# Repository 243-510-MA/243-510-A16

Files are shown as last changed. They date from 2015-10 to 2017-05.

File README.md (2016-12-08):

# 243-510-A16
243-510 Communications numériques sans fil - automne 2016 Collège de Maisonneuve

Notre projet est de réaliser un système dynamique contrôlable à distance à l'aide d'un réseau MiWi pour faciliter le travail et la vie des étudiants et professeurs du département du Génie électrique du Collège de Maisonneuve. Le projet comporte un système d'alarme qui s'enclenche lorsqu'il y a détection de mouvement, avec un gyrophare et un avertisseur sonore (buzzer), un contrôleur magnétique pour déverrouiller une porte, un contrôleur qui permet de contrôler un projecteur et une toile et l'envoi de messages prédéfinis à une adresse spécifique.

Parties fonctionnelles :

    Contrôle du projecteur (ON/OFF) à l'aide d'une communication série (RS-232)(BAUD 9600)(LSB(inverted?)) :

    Trames utilisées :

    Power on
        0x00 0xBF 0x00 0x00 0x01 0x02 0xC2
        0x02 0x00 0x00 0x00 0x00 0x02

    Power off
        0x00 0xBF 0x00 0x00 0x01 0x00 0xC0
        0x02 0x00 0x00 0x00 0x00 0x03

    Le contrôle de la toile à l'aide d'un servomoteur.
    Le contrôle de la porte à l'aide d'un électroaimant.
    L'envoi d'un questionnaire par le professeur aux élèves avec les réponses affichées sur l'écran du module professeur.
    Le gyrophare et le buzzer fonctionnent.
    Le chargeur du module étudiant (prototype) fonctionne.
    Les modules peuvent tous contrôler les options en réseau MiWi (PAN et end-devices).
	Le détecteur de mouvement fonctionne.
	L'envoi de messages prédéfinis à une adresse choisie.
	L'envoi de commandes MiWi à partir du terminal (sur le port série)

Parties non fonctionnelles :

	[PROBLÈME NON RÉSOLU]Lors de la réception de messages, on souhaitait afficher l'adresse source (de quel adresse le message est-il envoyé), mais on n'a pas trouvé comment effectuer cela.

Bugs connus à résoudre pour avoir un fonctionnement parfait :

    [PROBLÈME TROUVÉ, MAIS NON RÉSOLU]Le projecteur ne répond pas lorsque certaines conditions sont remplies. Si la lumière verte de "STATUS" est éteinte et que le bouton "power" est orange, le projecteur ne réagit pas aux communications séries (RS-232). La solution pour résoudre le problème est d'ajouter les trames de débuts manquantes dans l'envoi d'un message RS-232. Le contrôleur doit envoyer une trame de "wake-up" au projecteur à chaque 7 secondes environ pour s'assurer qu'il est prêt à "écouter" sur le bus. La trame de "wake-up à ajouter est : 0x00 0xBF 0x00 0x00 0x01 0x00 0xC0.
	[PROBLÈME TROUVÉ, MAIS NON RÉSOLU]Lors de la synchronisation de nouveaux fichiers sur GitHub, le fichier Demo911.c et le fichier Demo911.h se retrouvent supprimés du projet. Il y a un problème au niveau de la façon dont ont commit nos fichiers sur GitHub.
	
Étudiants contributeurs : François D'Amours-Lavoie, Mathieu Labelle, Laurent Brochu, Jonathan Chouinard, Alexandru Marin, Étienne Vaillancourt, Renaud Varin, Dominic Fournier, Dominik Boudreau-Perron, Gabriel Ahr, Alexia Brazeau, Samuel Proulx, Jean-Philippe Dagenais, Carlos Bedoya

Professeur contributeur : Frédéric Daigle

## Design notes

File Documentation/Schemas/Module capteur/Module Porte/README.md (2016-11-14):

Pour Calculer la Résistance nécessaire pour le 
courant de la base il faut utiliser la formule suivante
Ic = hfe * Ib

Ic= courant collecteur
hfe= Gain du transistor bijonction
Ib= Courant a la base

Dans notre utilisation, l'electro aimant consomme
200mA max. mais la limite du transistor est de 200mA
donc on a decicé de l'alimenter avec 190mA. 
Donc Ic=190mA

Pour calculer le hfe il faut utiliser le multimetre sur 
option NPN.   hfe = 189

avec la formule on deduit que Ib nécessaire est de 1mA.

ensuite pour trouver la resistance on utilise la loi de ohm.
R=V/I (il ne faut pas oublier de soustraire 0.7V de la tension
 au signal du a la chute de tension du transistor.

V= (3.3 - 0.7) = 2.6V

R= 2.6 / 1mA = 2600 Ohms.

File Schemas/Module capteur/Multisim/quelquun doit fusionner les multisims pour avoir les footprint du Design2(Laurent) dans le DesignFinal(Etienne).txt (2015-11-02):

quelquun doit fusionner les multisims pour avoir les footprint du Design2(Laurent) dans le DesignFinal(Etienne)

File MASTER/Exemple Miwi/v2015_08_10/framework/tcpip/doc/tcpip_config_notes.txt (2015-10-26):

Items that cannot be enabled in tcpip_config.h:

For Demo App:
None
  Following items cannot be enabled when using PIC 18:
  STACK_USE_SSL_SERVER
  STACK_USE_SSL_CLIENT
  STACK_USE_TCP_PERFORMANCE_TEST
  STACK_USE_ZEROCONF_LINK_LOCAL
  STACK_USE_ZEROCONF_MDNS_SD
  STACK_USE_GENERIC_TCP_CLIENT_EXAMPLE behaves incorrectly
  STACK_USE_TELNET_SERVER and STACK_USE_SNTP_CLIENT cannot be enable simultaneously. Either one of them can be enabled.

WiFi Console:
STACK_USE_HTTP2_SERVER
STACK_USE_SSL_SERVER can be enabled with cert file: custom_ssl_cert.c
STACK_USE_SSL_CLIENT can be enabled with cert file: custom_ssl_cert.c
STACK_USE_AUTOUPDATE_UART (only can not be enabled in MRF24WB)
STACK_USE_SNTP_CLIENT will make the console slow in some configurations

Easy Config:
STACK_USE_SSL_SERVER can be enabled with cert file: custom_ssl_cert.c
STACK_USE_SSL_CLIENT can be enabled with cert file: custom_ssl_cert.c

WiFi G Demo:
STACK_USE_UART
STACK_USE_UART2TCP_BRIDGE
STACK_USE_SSL_SERVER can be enabled with cert file: custom_ssl_cert.c
STACK_USE_SSL_CLIENT can be enabled with cert file: custom_ssl_cert.c
STACK_USE_FTP_SERVER (lack of EEPROM which is used by some functions)
STACK_USE_TELNET_SERVER (lack of LEDs or Buttons)
STACK_USE_UDP_PERFORMANCE_TEST (lack of LEDs or Buttons)

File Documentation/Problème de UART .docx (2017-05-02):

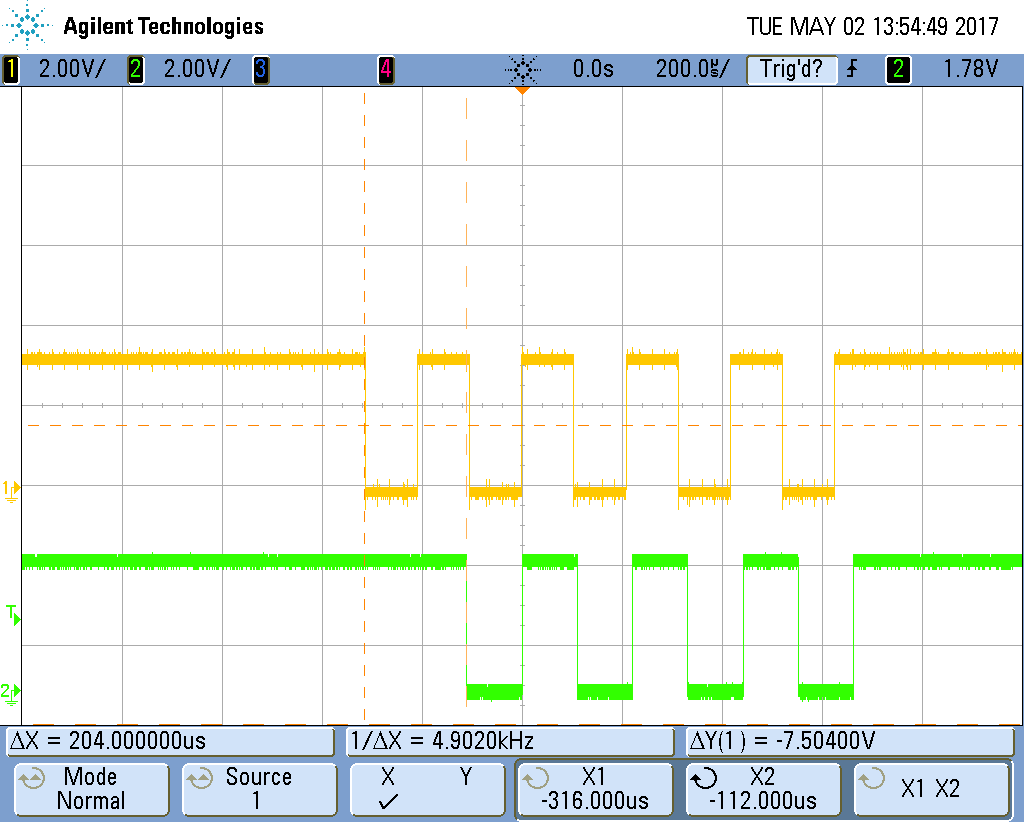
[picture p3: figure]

Problème de UART

Signal vert : moment ou le microcontrôleur utilisant le UART logiciel fait un échantillon de la broche de réception.

Signal jaune : Caractère 'U' envoyé à partir de Tera Term sur le port série

Explication :

Le UART matériel des modules MIWI est déjà utilisé par l'antenne MiWi, et il y en a un seul sur le PIC utilisé (PIC18F46J50). Il y a alors du code (soft_uart.c) pour un UART logiciel (fonctions avec le suffixe « A2_A1 « , tel que UART_Read_A2_A1) . Cependant, puisque c'est logiciel et qu'il n'est pas basé sur des temporisateurs, ainsi que le fait que la lecture de la broche ne peux pas se faire par interruption (cette broche là ne le permet pas et il n'y a qu'une broche d’interruption sur ce PIC), la lecture des données entrants n'est pas fiable du tout. L'envoi de données l'est un peu plus, mais pas à 100%. L'envoi de données peut se faire interrompre par des routines d'interruptions de temporisateurs ou d'interruptions externes (le UART de l'antenne MiWi par exemple).

Sur la capture d'écran, on voit que l'échantillonnage qui est supposé se faire après 150 us (50 us de start bit, + 100 us pour échantillonné au milieu du bit) se fait à 204 us, dans ce cas ci. Le moment d'échantillonnage variera selon le moment d'envoi des données sur la broche de réception du PIC ainsi que l'endroit dans le code ou le PIC est rendu à exécuter (variation du délai avant que le programme exécute « if(uart_kbhit()) ».

Idéalement, il faudrait un PIC différent qui a deux UART matériel, ou mettre le UART logiciel sur une broche qui peut être interrompue.

Une autre solution (possiblement) serait de suivre le modèle de la fonction « questionnaire_function » dans « student.c » . Il faudrait placer le « if(kbhit()) » à plusieurs place dans les autres fonctions exécutées par le module COMPUTER_CONTROL.

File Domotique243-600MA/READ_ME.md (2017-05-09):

243-600 Systèmes d'exploitation
===============================
Projet domotique
----------------
#Avant de continuer le projet, assurez vous d'avoir effectué toutes les installations nécéssaires sur le beaglebone qui sont sur le fichier => Étapes d'installation. 

Dans le cadre du cours 243-600 on doit ajouter des fonctionnalités au projet de la classe intelligente réalisé dans le cours de Communication numérique sans-fil. 
On doit être capables de faire:

*Une visualisation des conditions atmosphériques de la classe à partir de n'importe quel ordinateur connecté à Internet.
*Faire une visualisation de l'état de la Porte à partir de n'importe quel ordinateur connecté à internet
*Avoir la possibilité pour un professeur de verrouiller ou déverrouiller la classe à pârtir de n'importe quel ordinateur connecté à internet.
*Possibilite de savoir par internet qui est présent dans la classe
*Affichage d'un message envoyé par Internet sur l'écran OLED du Beaglebone
*Toute autre fonctionnalité jugée utile ou intéressante

Ce qui a été complété jusqu'a maintenant à la date du : 09/Mai/2017

* La visualisation des conditions atmosphériques de la classe à partir de n'importe quel ordinnateur connecté à internet.
>on a reussi à lire les données sur le capteur meteo BME_280 et de mettre les données >sur un fichier json. (Donnee_BME280.json) qui est sauvegarde sur /home/debian du >Beaglebone. Le code qui s'occupe de tout faire cela est dans le fichier Station_Meteo/ >Capteur. Capteur est le code source qui doit être compilé et mis dans le beaglebone.

*Visualisation de l'état de la porte à partir de n'importe quel ordinateur connecté à internet.
>Sur le dashboard: Classe intelligente sur Adafruit( username:243600MA MDP:temppwd)
>il y a un «feed» qui est un bouton(Status Porte) et auquel on peut changer l'état à >partir du beaglebone et l'inverse aussi sauf qu'il faut vérifier l'état à chaque >fois, >ce qui crée du traffic non-nécéssaire. 

*Possibilité, pour un proffesseur, de verouiller ou de deverrouiller la classe à partir de n'importe quel ordinnateur connecté à internet.
>CE QU'IL FAUT FAIRE: c'est trouver comment faire la communication avec le protocole >MQTT qui nous permettrait d'utiliser la fonction Subscribe. On retrouve l'information >sur:https://github.com/adafruit/io-client->python/blob/master/examples/mqtt_client.py
>Avec mqtt on aura pas besoin de toujours vérifier l'état puisque le server va dire au >Beaglebone dès qu'une modification a été faite sur le dashboard.

*Possibilité de savoir par internet qui est présent dans la classe
>Pour les modules MiWi, les modules en student sont capables d'envoyer leur addresse >MAC au module Computer Control a chaque minute. Le computer control les recoit mais  >fait rien à cause que ce n'est pas encore implementé. 
>il resterait a implementer un code qui envoie cette information au Beaglebone aussi >et a partir du Beaglebone envoyer cette info au Dashboard du serveur Adafruit.io 
>Il y a une document sur github qui explique le problème qu'il y a sur le UART du >Computer Control.

*Affichage d'un message envoyé par internet sur l'écran OLED du Beaglebone
>On est capables d'afficher un message sur le Beaglebone qui provient du Dashboard >sauf qu'ici encore on doit le vérifier au lieu de recevoir un avertissement qui >provient du serveur quand il a été changé. il faut trouver une facon de faire >fonctionner le MQTT

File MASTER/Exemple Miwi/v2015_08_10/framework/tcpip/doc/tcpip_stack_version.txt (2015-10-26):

********
Microchip TCP/IP Stack Version Log:
********

Note: Please file bug-reports/bug-fixes at http://support.microchip.com/ or post
      to the Microchip TCP/IP -> Ethernet Forum at http://forum.microchip.com/
      Look for stack updates at http://www.microchip.com/mla/

********
v5.45.00    August 2015
********
Changes:
1. Minor changes to fit latest version of XC8, XC16 and XC32 compilers.

********
v5.44.00    May 2015
********
Wi-Fi Changes:
1. For connection to AP in Infrastructure, WPS, or network redirection from SoftAP or Ad-Hoc mode, client station defaults to WPA-PSK/WPA2-PSK Auto when AP is in WPA-PSK, WPA2-PSK, WPA-PSK/WPA2-PSK Auto, or WPA-PSK/WPA2-PSK Mixed mode.
2. Improve DHCP Server to support up to 6 clients and recycle IP when lease expired or client disconnected.

Wi-Fi Notes:
1. MRF24WB WPA-PSK/WPA2-PSK Auto mode may not work when the target AP is set at WPA-PSK/WPA2-PSK Auto/Mixed mode.  The solution is to set WPA-PSK or WPA2-PSK mode in AP.
2. Current Wi-Fi Demo Projects do not support MPLAB Code Configurator.

Wi-Fi G Demo Improvements:
1. DHCP Server
    - support up to 6 clients
    - recycle lease IP when client disconnected - enable/disable this feature with #define CHECK_LINK_STATUS
    - longer ACK timeout to better accommodate busy wireless network
2. Wireless Security Mode
    - client station uses WPA-PSK/WPA2-PSK Auto when connecting to AP in WPA-PSK, WPA2-PSK, or WPA-PSK/WAP2-PSK Auto/Mixed mode

Fixes:
1. Fixed mDNS indexes overrun bug to handle incoming message with length greater than 8 bits value.

********
v5.43.00    July 2014
********
Changes:
1. Ported WiFi support from legacy MLA.
2. SNMP support has not been ported.
3. SSL is no longer supported for PIC18 and XC8.
4. Improve OTA update. Uses .txt as well as .bin.
5. Improve WPA/WPA2 mixed mode behavior.
7. TCPIP Configuration Wizard utility has not been ported.

Fixes:
1. WiFi G demo scan lock-up problem.
2. Address TCP 0 length lock-up problem.
3. Improve RawMoveComplete lock-up problem.
4. Fix wrong RSSI indications.
5. Address SSL 2048 problem.

********
v5.42.08    June 2013
********
Changes:
1. Clarify item#4 in v5.42.04 Oct 2012 release. Change is applicable to MRF24WB/G only.
   (MRF24WB/G) SSL client with RSA 2048bits is enabled by default. Applies only for PIC24/32. Not supported for PIC18.
2. (WiFi G Demo Board) Disable option WF_EASY_CONFIG_DEMO in WF_Config.h to resolve compilation error with IperfAppInit().

Fixes:
1. (MRF24WB) Resolve firmware 0x120C host scan bug : Host scan asserts when it is conducted after WPA-PSK fails due to key mismatch.
   Refer to WFScan.c and WFMgmtMsg.c.
2. (MRF24WB) Resolve reset problem bug. Modified WF_SetCE_N and WF_SetRST_N to first set the level, than configure pin as output.
   Refer to WFDriverPrv.h. This change is already available in WFDriverPrv_24G.h for MRF24WG in MLA v5.42.02 Aug 2012 release.
3. (MRF24W) Resolve WiFi Console demo IPERF issue bug fix : Enlarge generic tcp rx/tx buffer size. Refer to TCPIP MRF24W.h.
4. (MRF24W) Resolve EasyConfig bug fix for retry count when DISABLE_MODULE_FW_CONNECT_MANAGER_IN_INFRASTRUCTURE is enabled.
   Refer to function WFEasyConfigProcess() in WFEasyconfig.c
5. (MRF24W) Resolve handling of max length SSID of AP. Refer to WFEasyConfig.c and CustomHTTPApp.c

********
v5.42.06    Feb 2013
********
Changes:
1. (MRF24WG)   Due to memory constraints, all future RF module FW releases will follow this roll-out order
               (Odd number eg 0x3109, 0x310b) Differences: Supports Wi-Fi Direct (P2P). But no EAP and no multi-client support.
               (Even number eg 0x3108, 0x310a) Differences: Supports EAP (with MCHP approval) and multi-clients. But no Wi-Fi Direct support.
2. (MRF24WG)   Added new project Wifi G demo. Wifi G demo currently only support softAP function,
3. (MRF24WG)   In Wifi Console, for XC32-EX116-EAP_MRF24WG, supports security mode WF_SECURITY_WPA2_ENTERPRISE
               (EAP-PEAP/MSCHAPv2 and EAP-TTLS/MSCHAPv2) .
               Requires RF module FW version 0x3108 and even number releases. This requires special approval submitted to marketing.
4. (MRF24WG)   Supports multi-client DHCP server (max 4 clients). SoftAP supports up to max 4 client
               Requires RF module FW version 0x3108 and even number releases.
5. (MRF24WG)   softAP supports active scan. Requires RF module FW version 0x3108 and future releases.
6. (MRF24WG)   RF module FW version 0x3107 and future releases will NO longer support programming of regional domain via function
               WF_SetRegionalDomain() due to changes in FCC requirements, which does not allow programming of the regional domain.
7. (MRF24WB/G) Only WEP key index 0 is valid for security mode WEP.
8. (MRF24WG)   Created new event WF_EVENT_SOFT_AP_EVENT_SUBTYPE / WF_EVENT_SOFT_AP_EVENT, for softAP mode, to indicate client's
               status (connected or disconnected to softAP). Requires RF module FW version 0x3108 and later releases. If prior
               MLA releases are used with this new RF module FW version release, you need to port over this event handling in
               WFEVentHandler.c and WF_ProcessEvent() (WiFi EZConfig).
9.             Added full versions of RSA.c, ARCFOUR.c, and AES_PIC32MX.a to the TCP/IP Stack Distribution to support SSL and SNMPv3.
               Previously these files were distributed in a separate cryptographic code distribution.  These files are subject to the
               U.S. Export Administration Regulations and other U.S. law, and may not be exported or re-exported to certain countries
               or to persons or entities prohibited from receiving U.S. exports (including Denied Parties, entities on the Bureau of
               Export Administration Entity List, and Specially Designated Nationals).

Fixes:
1. (MRF24WG)   In EZConfig, SoftAP now supports Zeroconf & mDNS. Resolves wrong port issue.
               Search for keyword SOFTAP_ZEROCONF_SUPPORT.

********
v5.42.04    Oct 2012
********
Changes:
1.  (MRF24WB/G) Patch update features are added into MRF24WB0MA/B and MRF24WG0MA/MB.
    MRF24WB0MA/B (no RF module FW version update is necessary)
            Serial Port (Xmodem)
    MRF24WG0MA/B (Requires RF module FW version 3107 or later.)
            Serial Port (Xmodem), Web Client, Web Server
2.  (MRF24WB/G) FTP client is added into WiFi console demo app.
3.  (MRF24WB/G) Flexible scratch memory is used to allocate TCB.
4.  SSL client with RSA 2048bits is enabled by default. Applies only for PIC24/32. Not supported for PIC18.
5.  16-bit mode feature is available on PIC32.
6.  (MRF24WG) Enhance SoftAP with EZConfig features with pre-scan and redirection features.
    Change SoftAP address from 192.168.1.1 to 192.168.1.3
    Added WEP security, which requires RF module FW version 3107 or later.
    Refer to WF_Config.h for more information.
7.  Added support for PIC32MX6XX external PHY's: RTL 8201FL.
    Only RMII configuration is supported with RTLPHY8201FL PHY.
    This PHY driver works in Default Ethernet IO mode with PIC32MX675F512H .
    If Alternate Ethernet IO mode is used for other PIC devices, then configuration bit need
    to be changed w.r.t Alternate Ethernet IO.
    To get the status of MAC link with this PHY,  PHY Link Status need to be read twice.
    EthPhyGetLinkStatus(int refresh) API is used to read the PHY link status and for this PHY
    to read link status twice, the parameter refresh should be 1.

Fixes:
1.  (MRF24WG) SoftAP under EZConfig has pre-scan and redirection features. Able to be redirected to infrastructure mode AP.
2.  If SNMP_TRAP_DISABLED macro is enabled from TCPIP XXX.h file, there will be no TRAP table information for SNMP manager.
    That is SNMP agent won't send information related to trap. By default SNMP_TRAP_DISABLED macro is disabled.
3.  Fix typo error in v5.42.02
    (MRF24WG) SoftAP default address is changed from 169.254.1.1 to 192.168.1.1
4.  Fixed SNMP tabular issue if SNMP instances starts other than 0.
5.  Fixed ARP initialization bug that resulted in TCP packets sent to ETH MAC broadcast address.

********
v5.42.02    Aug 2012
********
Fixes:
1.  (MRF24WB/G) TCPIPConfig.exe is modified to support changes in macro definitions (CFG_WF_INFRASTRUCTURE, CFG_WF_ADHOC)
    used in WF_Config.h.
2.  (MRF24WB/G) Ad-hoc mode was left out in the TCPIP-Demo app. This mode is reinstated back into TCPIP-Demo app.
    2 files are changed.
    .\Microchip\Include\TCPIP Stack\WFDebugStrings.h
    .\TCPIP\Demo App\WF_Config.h
3.  (MRF24WB/G) SoftAP default address is changed from 192.168.1.1 to 169.254.1.1
4.  (MRF24WG) Apply SSL fix.
    Root cause is traced to be due to scratch pad memory to memory copy functions in WFMac_24G.c
5.  (MRF24WG) Reset fix.
     a.  In file WFDriverCom_24G.c, MRF24WG reset sequence is modified.
         - WFHardwareInit() does hard reset (putting I/O lines in correct state)
         - ChipReset() does soft reset
     b.  In file WFDriverPrv_24G.h, macros WF_SetCE_N() and WF_SetRST_N() modified to first set the output level,
         then set the I/O direction
6.  (MRF24WG) Applies to using PICDEMNet2 board and PIC18. Related to SPI interface settings.
     a.  In file WF_Spi.c, ConfigureSpiMRF24W() modified, for PIC18 only, to change the SPI clock idle state to low.
7.  (MRF24WB/G) When host attempts to read scan results while the module FW is in reconnecting state,  the module FW
    returns WF_ERROR_NO_STORED_BSS_DESCRIPTOR error. Reading scan results is only allowed in A) connected state; B) idle state.
    Fix is in WaitForMgmtResponseAndReadData().

    void WaitForMgmtResponseAndReadData(UINT8 expectedSubtype, UINT8 numDataBytes, UINT8 startIndex, UINT8 *p_data)
    {     ....................................
          /* check header result and subtype fields */
          WF_ASSERT(hdr.result  == WF_SUCCESS || hdr.result == WF_ERROR_NO_STORED_BSS_DESCRIPTOR);
          WF_ASSERT(hdr.subtype == expectedSubtype);
          ....................................
    }

********
v5.42       Jul 2012
********
Changes:
1.  All MPLAB 8 and MPLAB X projects have been modified to use the XC16 and XC32 compilers.
2.  The colon character ":" has been added as a valid terminator for an IP address in
    the StringToIPAddress function.
3.  (MRF24WB/G) PIC18 is only supported with "TCPIP Demo App".
    MRF24WB0MA/MB works on PICDEM PIC18 Explorer.
    MRF24WG0MA/MB works on PICDemNet2 PIC 18 but has issues with PICDEM PIC18 Explorer.
4.  (MRF24WB/G) Enhanced debug messages providing more details such as authentication or association
     failues, etc.
5.  (MRF24WB/G) Added option to disable module FW connection manager by adding "#define DISABLE_MODULE
    _FW_CONNECT_MANAGER_IN_INFRASTRUCTURE".
6.  (MRF24WB/G) Added option to derive real key from pass-phrase in host side by adding "#define DERIVE
    _KEY_FROM_PASSPHRASE_IN_HOST".
7.  (MRF24WB/G) Enabled WEP security for EasyConfig Ad-hoc connection
8.  (MRF24WB/G) Added support for MRF24WG0MA/MB, a superset of MRF24WB0MA/MB (MRF24WB).
    Required to add to project definition files (#define MRF24WG).
    Ranges are different from MRF24WB0MA/MB.
    i.   Valid RSSI Range : 43 ~ 128 (max)     (WF_ScanGetResult())
    ii.  Max transmit power range : 0 ~ 18 dbm (WF_TxPowerSetMax())

    MRF24WG0MA/MB enhancements are above and beyond on those features listed above.
    a.   Added WPS(1.0) security method (#define WF_SECURITY_WPS_PUSH_BUTTON & WF_SECURITY_WPS_PIN )
         (TCPIP demo + console demo).
    b.   Added Wi-Fi Direct (P2P) function in the GC (group client) role
         (#define MY_DEFAULT_NETWORK_TYPE    CFG_WF_P2P)
         (TCPIP demo + console demo)
    c.   Added simplified basic SoftAP functionality (WF_SOFT_AP).
         Current features are 1 client STA, open security and no routing.
         (Easy config demo)
    d.   Selection of support for 16 (max) software multicast filters (ENABLE_SOFTWARE_MULTICAST_FILTER )
         or 2 hardware multicast filters. RTS or ES release requires software patch.

Fixes:
1.  The BigInt_helper.S file will now correctly include the processor include files for the
    PIC24E and dsPIC33E architectures.
2.  Fixed bug in TCP state machine that corrupted the sequence number when client socket is closed.
3.  Fixed bug in BerkeleiAPI.c::sendto() that checked for the wrong UDP socket to be opened.
4.  (All parts including RTS or ES release) MRF24WG0MA/MB requires PLL work-around initialization code.
    Please refer to July/2012 release.
5.  (All parts including RTS or ES release) MRF24WG0MA/MB needs to update stack from July/2012 release
    to cater for SSL.
6.  (MRF24WB/G) Fixed stack issues encountered in Stack version v2012-04-03 and older.
    Code fix is needed in WF_CPSetElements() API. Modification is as below.

    void WF_CPSetElements(UINT8 CpId, tWFCPElements *p_elements) {
         UINT8 elements[sizeof(tWFCPElements) + 2];
         WF_ASSERT(p_elements->ssidLength <= WF_MAX_SSID_LENGTH);
         memset(elements, 0, sizeof(elements));
         memcpy(elements, p_elements, sizeof(*p_elements));
         LowLevel_CPSetElement(CpId,                 /* CP ID */
                               WF_CP_ELEMENT_ALL,    /* Element ID */
                               (UINT8 *)elements,    /* pointer to element data */
                               sizeof(elements));    /* number of element data bytes */
     }

    Code fix is also needed in WaitForMgmtResponse() API (WFMgmtMsg.c). Refer to description
    of this fix is in the Supplementary TCPIP Help folder.

Known Problems:
1.  Telnet server module does not implement a lot of Telnet functions.  As a
    result, it will likely not display correctly or work at all with some Telnet
    clients.  The server was tested with the Microsoft telnet.exe utility which
    is provided with Microsoft Windows.
2.  If the DHCP client and DHCP server are used at the same time and you connect
    two similar boards to each other (ex: two PICDEM.net 2 boards connected via
    a crossover cable), a race condition can occur where both nodes will disable
    their DHCP server and neither board will get a successful DHCP lease.  If
    this unlikely scenario occurs, as a work around, simply reset one of the
    boards to reenable it's DHCP server.
3.  LCDBlocking.c timing for the LCD_E_IO enable signal is too fast to meet
    published data sheet limits for various LCD controllers when compiling for
    a PIC32 running at > 43MHz.  Despite this potential timing violation, the
    LCD does normally work correctly on the precompiled PIC32 demos for the
    Explorer 16 at 80MHz.
4.  For PIC32 implementations, depending on the configuration, it is possible that the
    MACGetFreeRxSize() returns a value greater than 64 KB.
    For backward compatibility reasons the stack uses a 16 bit value to check the returned value
    and it won't work corretly.
5.  Limiting the number of UDP sockets to 8 in the stack demos may prevent SNMP trap
    functionality.  If this occurs, you can increase the MAX_UDP_SOCKETS definition in
    TCPIPConfig.h to 10 (if your system will support the increased data memory usage)
    to fix this issue.
6.  The SNMP mib file's date and version parameter does not match the date/version of
    the current stack release.
7.  (MRF24WG0MA/MB) RTS or ES release requires software patch for multicast filters.
8.  (MRF24WG0MA/MB) Under softap option with easy config demo, unable to connect to infrastructure mode AP.
9.  Certain APs have power save issue with reconnect. Please refer to AP compatibility list.

********
v5.41.02    Apr 2012
********
Fixes:
1.  Added the Bigint helper libraries for C30 into the stack source folder to prevent
    linker errors in 16-bit projects that include those libraries.

Known Problems:
1.  Telnet server module does not implement a lot of Telnet functions.  As a
    result, it will likely not display correctly or work at all with some Telnet
    clients.  The server was tested with the Microsoft telnet.exe utility which
    is provided with Microsoft Windows.
2.  If the DHCP client and DHCP server are used at the same time and you connect
    two similar boards to each other (ex: two PICDEM.net 2 boards connected via
    a crossover cable), a race condition can occur where both nodes will disable
    their DHCP server and neither board will get a successful DHCP lease.  If
    this unlikely scenario occurs, as a work around, simply reset one of the
    boards to reenable it's DHCP server.
3.  LCDBlocking.c timing for the LCD_E_IO enable signal is too fast to meet
    published data sheet limits for various LCD controllers when compiling for
    a PIC32 running at > 43MHz.  Despite this potential timing violation, the
    LCD does normally work correctly on the precompiled PIC32 demos for the
    Explorer 16 at 80MHz.
4.  For PIC32 implementations, depending on the configuration, it is possible that the
    MACGetFreeRxSize() returns a value greater than 64 KB.
    For backward compatibility reasons the stack uses a 16 bit value to check the returned value
    and it won't work corretly.
5.  Limiting the number of UDP sockets to 8 in the stack demos may prevent SNMP trap
    functionality.  If this occurs, you can increase the MAX_UDP_SOCKETS definition in
    TCPIPConfig.h to 10 (if your system will support the increased data memory usage)
    to fix this issue.
6.  The SNMP mib file's date and version parameter does not match the date/version of
    the current stack release.

********
v5.41       Feb 2012
********
Changes:
1.  Added socket number validation to TCP functions.
2.  Removed the WiFi projects from the Energy Monitoring and WebVend demos.
3.  Added the "-mperipheral-libs" linker option to C32 projects.
4.  Moved AES library and header files used by SNMPv3 from the "Crypto" source and
        include folders to the to the "TCPIP Stack" source and include folders.
5.  Changed SNMP MIB trap number from 7 to 0.
6.  Changed SNMP MIB SYOBJECTID to 43.6.1.4.1.17095.1 (added .1).
7.  Updated MPFS2 Utility to make path settings persistent.
8.  Changed default channel list from {1,6,11} to {1,2,3,4,5,6,7,8,9,10,11} for
    FCC domain
9.  Added support for WEP with Shared Key
10. Added new command "iwconfig scan" & "iwconfig scanresults"
11. Added gRFModuleVer1209orLater" flag to identify version 1209 and later
    specific API's.
12. Added the following 1209 and later specific API:
    a) WF_CPSetWepKeyType()
    b) WF_CMGetConnectContext()
    c) WFEnableBroadcastProbeResponse()
    d) WFEnableAggressivePowerSave()
    e) WF_CPSetSsidType()
    f) WFEnableDeferredPowerSave()
    g) WF_FixTxRateWithMaxPower()

Fixes:
1.  Updated MPFS2 Utility path strings for Mac/Linux compatibility.
2.  Iperf - Resolved application crash due to network disconnection.
3.  Host Scan - More robust and prevent system hang up.  #define WF_HOST_SCAN.
4.  Power Save - Improvements with Aggressive PS mode, and better handling of
    PS in host code.
5.  Host connect & disconnect - Prevent system hang.
6.  DHCP Refresh - Better handling of DHCP session in PS mode, and issue DHCP
    renewal any STA reconnect with AP.

Known Problems:
1.  Telnet server module does not implement a lot of Telnet functions.  As a
    result, it will likely not display correctly or work at all with some Telnet
    clients.  The server was tested with the Microsoft telnet.exe utility which
    is provided with Microsoft Windows.
2.  If the DHCP client and DHCP server are used at the same time and you connect
    two similar boards to each other (ex: two PICDEM.net 2 boards connected via
    a crossover cable), a race condition can occur where both nodes will disable
    their DHCP server and neither board will get a successful DHCP lease.  If
    this unlikely scenario occurs, as a work around, simply reset one of the
    boards to reenable it's DHCP server.
3.  LCDBlocking.c timing for the LCD_E_IO enable signal is too fast to meet
    published data sheet limits for various LCD controllers when compiling for
    a PIC32 running at > 43MHz.  Despite this potential timing violation, the
    LCD does normally work correctly on the precompiled PIC32 demos for the
    Explorer 16 at 80MHz.
4.  For PIC32 implementations, depending on the configuration, it is possible that the
    MACGetFreeRxSize() returns a value greater than 64 KB.
    For backward compatibility reasons the stack uses a 16 bit value to check the returned value
    and it won't work corretly.
5.  Limiting the number of UDP sockets to 8 in the stack demos may prevent SNMP trap
    functionality.  If this occurs, you can increase the MAX_UDP_SOCKETS definition in
    TCPIPConfig.h to 10 (if your system will support the increased data memory usage)
    to fix this issue.
6.  The SNMP mib file's date and version parameter does not match the date/version of
    the current stack release.

********
v5.36.4     Oct 2011
********
Changes:
1.  SNMPNotify() is updated to support ASCII string varible type for
    both TRAPv1 and TRAPv2.ASCII string address pointer is assigned to argument
    val(SNMP_VAL) of SNMPNotify().
2.  The SSL module has been updated to support 1024-bit RSA key lengths for server and
    client on all architectures.  PIC32 microcontrollers now support client/server
    RSA key lengths of 2048 bits.  NOTE: To support these changes, you must manually
    modify your copy of RSA.c.  A description of the required changes ("Required SSL
    Changes.pdf") can be found in your Microchip Applications Libraries installation
    directory in the "\Microchip\Help\Supplementary TCPIP Help" subdirectory.

Fixes:
1.  SNMP local variable community length increased with plus one.SNMP warnings
    has been removed for the compiler version C32 2.01 for zero optimisation.
2.  Updated MPFS2.jar and mib2bib.jar to support Java version 1.7.
3.  Fixed MPFS2.jar offset issue for fileRcrd.bin and dynRcrd.bin file and it was
    due to the file which has zero dynamic variable.Fixed Crimson editor problem
    with webPage2 folder where user couldn't save files using Crimson Editor
    if the WebPages2 folder that contained those files was selected in the MPFS2
    utility.
4.  MPFS2.jar file was getting hanged for the zero file size access.Now Zero file
    size also is the part of the respective generated files.

Known Problems:
1.  Telnet server module does not implement a lot of Telnet functions.  As a
    result, it will likely not display correctly or work at all with some Telnet
    clients.  The server was tested with the Microsoft telnet.exe utility which
    is provided with Microsoft Windows.
2.  If the DHCP client and DHCP server are used at the same time and you connect
    two similar boards to each other (ex: two PICDEM.net 2 boards connected via
    a crossover cable), a race condition can occur where both nodes will disable
    their DHCP server and neither board will get a successful DHCP lease.  If
    this unlikely scenario occurs, as a work around, simply reset one of the
    boards to reenable it's DHCP server.
3.  LCDBlocking.c timing for the LCD_E_IO enable signal is too fast to meet
    published data sheet limits for various LCD controllers when compiling for
    a PIC32 running at > 43MHz.  Despite this potential timing violation, the
    LCD does normally work correctly on the precompiled PIC32 demos for the
    Explorer 16 at 80MHz.
4.  For PIC32 implementations, depending on the configuration, it is possible that the
    MACGetFreeRxSize() returns a value greater than 64 KB.
    For backward compatibility reasons the stack uses a 16 bit value to check the returned value
    and it won't work corretly.
5.  Limiting the number of UDP sockets to 8 in the stack demos may prevent SNMP trap
    functionality.  If this occurs, you can increase the MAX_UDP_SOCKETS definition in
    TCPIPConfig.h to 10 (if your system will support the increased data memory usage)
    to fix this issue.
6.  The SNMP mib file's date and version parameter does not match the date/version of
    the current stack release.

********
v5.36.2     July 2011
********
Changes:
1.  Removed the Google PowerMeter and Google PowerMeter EZConfig demos.  Google, Inc.
    has deprecated Google PowerMeter and has expressed the intent to remove access to
    it on September 16, 2011.  To obtain Microchip Technology's Google PowerMeter
    reference implementation, you can download the June 2011 Microchip Application
    Libraries archived release from www.microchip.com/mal.
2.  Modified the Energy Monitoring demo to remove Google PowerMeter functionality.
    The demo will still display measured power data on its internal web page.
3.  Updated the TCP/IP Stack Performance table to use the testing methodology from
    previous releases.  More information is available in the TCP/IP Stack Help file.
4.  gSnmpNonMibRecInfo[] has been moved from snmp.c file to CustomSNMPApp.c file and
    SNMP_MAX_NON_REC_ID_OID macro has been moved from snmp.h file to CustomSNMPApp.c file.
    gSnmpNonMibRecInfo[] is used to list the static variables parent OID strings which are
    not part of mib.h file. This structure is used to restrict the access to the SNMPv3 objects
    from SNMPv2c and SNMPv1 version requests. Macro STACK_USE_SMIV2 is used to support
    gSnmpNonMibRecInfo[] with MODULE-IDENTITY number. For V5.31 STACK_USE_SMIV2 need to commented.
5.  Removed the SPI2CON register freeze-on-halt bit macro from the SPIFlash, RAM, and EEPROM
    driver files to provide compatibility with C32 v2.00.

Fixes:
1.  Removed the MPFSImg2 files from the MPLAB X C18/C30 projects so that the projects
    will compile.  Disabled MPFSImg2.c for PIC32 Explorer 16 projects.
2.  Added a heap and minimum stack size for the PIC32 Ethernet Starter Kit MPLAB X
    project.
3.  The TCP/IP Stack Help File's performance table has been updated using the same
    test procedure used in previous releases.

Known Problems:
1.  Telnet server module does not implement a lot of Telnet functions.  As a
    result, it will likely not display correctly or work at all with some Telnet
    clients.  The server was tested with the Microsoft telnet.exe utility which
    is provided with Microsoft Windows.
2.  If the DHCP client and DHCP server are used at the same time and you connect
    two similar boards to each other (ex: two PICDEM.net 2 boards connected via
    a crossover cable), a race condition can occur where both nodes will disable
    their DHCP server and neither board will get a successful DHCP lease.  If
    this unlikely scenario occurs, as a work around, simply reset one of the
    boards to reenable it's DHCP server.
3.  LCDBlocking.c timing for the LCD_E_IO enable signal is too fast to meet
    published data sheet limits for various LCD controllers when compiling for
    a PIC32 running at > 43MHz.  Despite this potential timing violation, the
    LCD does normally work correctly on the precompiled PIC32 demos for the
    Explorer 16 at 80MHz.
4.  For PIC32 implementations, depending on the configuration, it is possible that the
    MACGetFreeRxSize() returns a value greater than 64 KB.
    For backward compatibility reasons the stack uses a 16 bit value to check the returned value
    and it won't work corretly.
5.  Limiting the number of UDP sockets to 8 in the stack demos may prevent SNMP trap
    functionality.  If this occurs, you can increase the MAX_UDP_SOCKETS definition in
    TCPIPConfig.h to 10 (if your system will support the increased data memory usage)
    to fix this issue.
6.  The SNMP mib file's date and version parameter does not match the date/version of
    the current stack release.

********
v5.36       2 June 2011
********
Changes:
1.  Because of changes to the SHOUTcast server configuration, the Internet Radio
    demo is no longer functional.  This demo has been retained in the stack distribution
    to provide a TCP/IP code example.
2.  The UDP module will now perform address resolution and DNS querying automatically.
    As a result, the UDP module APIs have changed.  The UDPOpenEx function provides this
    additional functionality.  Please consult the TCP/IP Stack Help File's
    "Stack API > UDP" topic for more information.
3.  The UDPOpen macro has been added to conform to the legacy UDPOpen interface.
4.  The Announce, BerkeleyAPI, DHCP client/server, DNS client/server, NBNS, Reboot,
    SNMP, SNTP, TFTPc, UDPPerformanceTest, and ZeroConf modules have been updated to
    use the new UDP API.  The iPerf demo has also been updated.
5.  The MPFS Classic and HTTP(1) modules have been removed from the stack.  Function-
    ality to support these modules has also been removed from the TCP/IP Stack software
    tools.  MPFS2 and HTTP2 are still supported.
6.  The UARTConfig demo module has been updated to upload MPFS2 images to the demo board
    in place of MPFS Classic images.
7.  To facilitate linking on PIC18 platforms, the number of UDP sockets in demo projects
    has been reduced from 10 to 8.
8.  The SNMP Stack application and mib2bib.jar PC utility now both support 1024
    dynamic IDs.
9.  SNMP_DEMO_TRAP is a new dynamic variable added to the snmp.mib file to support SMIv2
    with TRAPv2.  This will correct a previously existing issue viewing traps with the
    iReasoning MIB browser.  As per those changes, the mchp.mib file has been modified
    to support the SMIv2 standard.  This mib includes MODULE-IDENTITY which will provide
    MICROCHIP and MIB information.  snmp.mib also includes MODULE-IDENTIY(1), a new
    number (1) to the existing OID after ENTERPRISE-ID(17095).
10. Added a preprocessor check that will include the ultoa function if a version of the
    C32 compiler earlier than 1.12 is used.
11. Modified the WiFi module to use separate retry counters for AdHoc and Infrastructure
    modes.
12. Modified Berkeley API module to accept IPPROTO_IP as a valid protocol for the socket
    function.  The code will determine the protocol type from the socket type (datagram
    or stream).
13. Created MPLAB X projects corresponding to most MPLAB 8 projects and configurations.
    These projects are located in the MPLAB.X subfolder in the associated demo project
    directory.  The MPLAB X import wizard can be used to create MPLAB X projects from
    MPLAB 8 projects that don't have an analogue in the new demo project folders.
14. Added project support for the dsPIC33E and PIC24E architectures.
15. All TCP/IP Stack demo projects have been moved to the "TCPIP" subdirectory
    in the stack installation directory.
16. Created Java versions of several TCP/IP tools to provide cross-platform support. The
    TCP/IP Configuration Wizard has not been ported to Java; thus, it is only available
    for Windows users.
17. To prevent issues with path length, MPLAB 8 project names have been changed.
    A list of the abbreviations used in the project names is available in the MAL help
    folder (Microchip Solutions/Microchip/Help/Abbreviations.htm).  The names of the
    HardwareProfile and TCPIPConfig configuration files have been abbreviated as well.
18. Changed the configuration inclusion macros used by the TCP/IP Stack demo projects to
    match the terms used in the project/configuration names.
19. The "Alternative Configurations" subfolders in most demo projects has been renamed
    to "Configs."
20. Added a Google PowerMeter demo for use with the PIC18F87J72 Energy Monitoring PICtail.
21. The Web Preview tool is no longer included with the stack.

Fixes:
1.  Fixed a DHCP Server (DHCPs.c) lease leak problem that would occur when
    STACK_USE_ZEROCONF_LINK_LOCAL was defined.  This problem would have
    resulted in the DHCP server stop giving out any leases until being rebooted.
2.  Updated the PIC32MX6XX/7XX external PHY SMSC 8720LAN reference design.
3.  Fixed bug with window expecting MACGetFreeRxSize() to return values < 32KB.
4.  Fixed a type casting bug with the CalcIPChecksum function that would cause
    an incorrect TX checksum if the checksum value overflowed again after adding
    the carry bits to the checksum value.
5.  Fixed a bug in the AutoIP module that may have prevented the module from
    correctly defending its own address.
6.  Added a check to the Announce module to ensure the MAC layer is linked before
    attemping to transmit an Announce message.
7.  Fixed a bug in the ETH97J60 MACPut function.
8.  Added an additional preprocessor check in a debug menu setting in WF_Spi.c
    to prevent a build error.
9.  Added a fix to the Google PowerMeter demo code to restore SNTP timestamp
    sourcing if SNTP is enabled.  Previously, it would be overwritten by
    a possibly invalid HTTP timestamp.

Known Problems:
1.  Telnet server module does not implement a lot of Telnet functions.  As a
    result, it will likely not display correctly or work at all with some Telnet
    clients.  The server was tested with the Microsoft telnet.exe utility which
    is provided with Microsoft Windows.
2.  If the DHCP client and DHCP server are used at the same time and you connect
    two similar boards to each other (ex: two PICDEM.net 2 boards connected via
    a crossover cable), a race condition can occur where both nodes will disable
    their DHCP server and neither board will get a successful DHCP lease.  If
    this unlikely scenario occurs, as a work around, simply reset one of the
    boards to reenable it's DHCP server.
3.  LCDBlocking.c timing for the LCD_E_IO enable signal is too fast to meet
    published data sheet limits for various LCD controllers when compiling for
    a PIC32 running at > 43MHz.  Despite this potential timing violation, the
    LCD does normally work correctly on the precompiled PIC32 demos for the
    Explorer 16 at 80MHz.
4.  For PIC32 implementations, depending on the configuration, it is possible that the
    MACGetFreeRxSize() returns a value greater than 64 KB.
    For backward compatibility reasons the stack uses a 16 bit value to check the returned value
    and it won't work corretly.
5.  Limiting the number of UDP sockets to 8 in the stack demos may prevent SNMP trap
    functionality.  If this occurs, you can increase the MAX_UDP_SOCKETS definition in
    TCPIPConfig.h to 10 (if your system will support the increased data memory usage)
    to fix this issue.
6.  The SNMP mib file's date and version parameter does not match the date/version of
    the current stack release.

********
v5.31       19 October 2010
********
Changes:
1.  Reorganized demo projects.  The TCPIP ENCX24J600 Demo App, TCPIP PIC32 ETH
    Demo App, and TCPIP WiFi Demo App projects in stack versions 5.25 and prior
    have all been merged into the TCPIP Demo App folder.  All four of these
    projects were almost identical to each other, with the primary difference
    being the network interface controller the projects were preconfigured to
    support.  In this 5.31 TCP/IP Stack release, each hardware combination now
    has its own MPLAB IDE project in the TCPIP Demo App folder.
2.  Reorganized HardwareProfile.h and TCPIPConfig.h structure for the TCPIP Demo
    App, TCPIP Google PowerMeter Demo App, and TCPIP WebVend App projects.  Now,
    instead of having one massive HardwareProfile.h file that supports a
    multitude of hardware platforms simultaneously, simple individual
    hardware profiles have been created for specific hardware combinations and
    placed in the "Alternative Configurations" sub-folder.  The correct hardware
    profile or TCPIP config file is selected by #including "HardwareProfile.h"
    or "TCPIPConfig.h" as in previous stack versions.  However, the active
    hardware profile or config file from the Alternative Configurations folder
    is selected by a preprocessor macro defined in the MPLAB project settings
    (passed on the command line to the compiler).
3.  Added HTTP_SAVE_CONTEXT_IN_PIC_RAM option to TCPIPConfig.h (HTTP2 server
    module).  This option, when enabled, will increase HTTP2 server performance
    when servicing multiple simultaneous connections at the expense of using
    more PIC RAM.
4.  Added automatic TPIN+/- polarity swapping logic to ETH97J60.c driver for
    PIC18F97J60 family devices.  Some 3rd party Ethernet switches, routers, and
    end devices have their TX+/- pins wired backwards such that the remote TX+
    signal connects to the PIC TPIN- pin and the remote TX- signal connects to
    the PIC TPIN+ pin.  Because 10BaseT Ethernet signaling is polarized and the
    PIC18F97J60 family does not implement an auto-polarity feature, this
    normally prevents all RX communications with these non-IEEE 802.3 compliant
    link partners.  To work around this incompatibility, it is possible to
    implement circuitry to swap the RX+ and RX- signals before reaching the
    TPIN+ and TPIN- pins.  The PICDEM.net 2 Rev 6 reference design includes this
    necessary circuitry (U6, U7, R54, and RX_SWAP GPIO output pin from PIC).
    This stack version automatically controls the RX_SWAP signal based on the
    ETH_RX_POLARITY_SWAP_TRIS and ETH_RX_POLARITY_SWAP_IO definitions in
    HardwareProfile.h.  If these macros are undefined, then the automatic
    polarity swapping feature is disabled in the ETH97J60.c driver.
5.  Added portable LFSRRand() and LFSRSeedRand() public functions to Helpers.c
    and removed all references to C rand() and srand() functions.  The C rand()
    function returns a 15 bit integer on 8 and 16 bit PICs, but a 31 bit integer
    on PIC32s.  The LFSRRand() function returns a 16-bit integer, regardless of
    which PIC you are using.
6.  Added support for various SST/Microchip brand SST25xxxxx SPI Flash chips to
    SPIFlash.c driver.  Previously only devices supporting the Auto Address
    Increment (AAI) Word Program opcode (0xAD) would work.  Now, devices such as
    the SST2525VF010A should work, which require the AAI Byte program opcode
    (0xAF) instead.
7.  Removed support for Spansion brand SPI Flash chips in the SPIFlash.c driver.
    If your application is already using one of these devices, continue to use
    the SPIFlash.c/.h files from TCP/IP Stack 5.25.  These older files are API
    compatible with the current version, so can be dropped in by simply
    overwriting the SPIFlash.c and SPIFlash.h files.
8.  Removed a -4 offset from the advirtised TCP Maximum Segment Size option
    (MSS) and TCP_MAX_SEG_SIZE_RX configuration value in TCP.c.  The default
    TCP MSS advertised is now 536 instead of 532.
9.  For Wi-Fi projects in the TCPIP Demo App folder, changed
    MY_DEFAULT_LIST_RETRY_COUNT to WF_RETRY_FOREVER instead of 3.  This
    changes default connection behavior to keep trying to connect instead of
    just trying 3 times which makes more sense for demonstration.
10. Changed WF_Connect() beacon timeout to 40.
11. IFConfig command in TCPIP WiFi Console Demo App modified to return
    application-perspective MAC address from the AppConfig structure, and not
    the Wi-Fi serialized MAC address (they may not match if user desired custom
    MAC).
12. Updated the TCP/IP Configuration Wizard.  The user can now configure
    wireless settings and stack settings seperately.  Because of the changes to
    the TCPIPConfig.h file, the user must now select the specific copy of
    TCPIPConfig.h (or any of its variants) instead of selecting a project
    directory. Added the ability to select WF_RETRY_FOREVER in the Wi-Fi
    configuration settings.  Added a selection parameter for BSD socket count.
    Added validation to check for the proper number of Berkeley sockets and TCP
    performance test sockets in the socket configuration screen (Advanced
    Settings) if either of these features are enabled.  Added the ability to
    create sockets of the same type with different TX/RX buffer sizes in the
    socket configuration screen.
13. Updated the TCPIP WebVend Demo App to support Wi-Fi in several
    configurations.
14. Modified the Google PowerMeter demo to automatically determine the
    date/time from the HTTP module if the date/time cannot be obtained from the
    SNTP module.
15. Added a new Google Map project example to the Combo Demos folder.  This
    example runs on a PIC24FJ256DA210 Development Board + Fast 100Mbps Ethernet
    PICtail Plus (or Ethernet PICtail Plus) + Truly 3.2" 240x320 display,
    TFT_G240320LTSW_118W_E (or Powertip 4.3" 480x272 display,
    PH480272T_005_I11Q).  It also can run on the PIC32 Multimedia Expansion
    Board + PIC32 Ethernet Starter Kit.  This demo connects to the Internet,
    sends an HTTP query for a specific map tile to the Google Static Maps API,
    and then displays the compressed tile to the graphics display.  For more
    information, see the "Getting Started - Running the Graphics Google Map
    Demo.htm" file in the Combo Demos\Google Map folder.
16. Added preliminary SNMPv3 module.  This module, enabled with the
    STACK_USE_SNMPV3_SERVER option in TCPIPConfig.h, implements the Simple
    Network Management Protocol, version 3.  Among other things, SNMPv3 adds
    secure authentication and cryptographic privacy as compared to SNMPv2C.
    This implementation currently only supports AES encryption (no DES support).
    It also has only been tested with the PIC32 Ethernet Starter Kit (TCPIP
    Demo App - C32 - PIC32_ENET_SK_DM320004_INTERNAL_ETHERNET.mcp MPLAB IDE
    project).  SNMPv3 on PIC18, PIC24, and dsPIC platforms are not supported at
    this time.  Because AES encryption has specialized United States export
    requirements, this TCP/IP Stack release does not include the required AES
    library to enable SNMPv3.  To obtain the needed AES library, you must
    purchase SW300052 v2.6 or later.  Older v2.5 and previous versions include
    AES related files on them, but do not include the new AES files required by
    SNMPv3.  For more information on using SNMP, refer to the TCP/IP Stack Help
    (Demo Information -> Available Demos -> TCPIP Demo App -> Demo Modules ->
    Network Management (SNMP) Server).
17. Altered the SaveAppConfig() function in MainDemo.c to store a more robust
    signature to EEPROM/SPI Flash when saving the AppConfig structure.  In v5.25
    and prior stack versions, when EEPROM or SPI Flash memory was available, the
    stack would automatically write a one byte marker character to address
    0x000000 in the EEPROM/Flash indicating if a valid AppConfig structure was
    stored in the non-volatile memory.  This resulted in the EEPROM/Flash
    contents being organized like the following:
        Address                 Data Contents
        ===================     ==============================================
        0x000000:               Marker Byte
        0x000001:               AppConfig structure
        MPFS_RESERVE_BLOCK:     Start of MPFS/MPFS2 image containing web pages
    In this stack version, EEPOM/Flash contents will now contain:
        Address                 Data Contents
        ===================     ==============================================
        0x000000:               Length of AppConfig structure (16-bit integer)
        0x000002:               IP checksum of the AppConfig default values, as
                                defined in TCPIPConfig.h and WF_Config.h
                                (16-bit integer).
        0x000004:               IP checksum of the subsequent EEPROM/Flash
                                bytes of the AppConfig values.
        0x000006:               AppConfig structure
        MPFS_RESERVE_BLOCK:     Start of MPFS/MPFS2 image containing web pages
   The additional checkums allow automatic detection to occur if you change one
   of the values in TCPIPConfig.h or WF_Config.h that affects AppConfig.  If
   you change one of the values in code, then upon boot up, the application
   will automatically detect this change and start using the values that you
   selected in code.  If, at run time, you decide to change the AppConfig
   values and commit the changes to EEPROM/Flash, then the stack will
   subsequently use the run-time saved values on future reboots.  The checksum
   at offset 0x000004 ensures that if any corrupted AppConfig contents are
   found in EEPROM/Flash (ex: power is lost between writing the signature
   structure and actual AppConfig structure, or code unintentionally overwrites
   something in the AppConfig memory area), then the original defaults defined
   in TCPIPConfig.h and WF_Config.h will be used instead of the corrupted
   values.  This EEPROM/SPI Flash change affects all projects except TCPIP
   Internet Radio App, TCPIP Internet Bootloader App, and all PIC32 Starter Kit
   projects since these projects do not have or use external EEPROM or SPI
   Flash memory.

Fixes:
1.  Fixed a UDP bug in which a transmitted packet would have been addressed
    to the wrong destination node if the UDP socket received a broadcast packet
    from a different remote node from the last received packet, but using the
    same source port number as the last received packet.  The
    FindMatchingSocket() function in UDP.c will now always change the local
    socket parameters to send to the most recent remote node's unicast IP
    address, regardless of if the last received packet was addressed to a
    multicast or broadcast destination.  Thanks go to Billy Walton for reporting
    this erroneous behavior.  If you wish to change the destination IP/MAC
    addresses or port number for a UDP packet that you are ready to send, write
    the new parameters to the UDPSocketInfo[SocketHandle] global structure
    before calling UDPFlush().  This structure contains remoteNode and
    remotePort parameters for the remote IP address/MAC address and remote UDP
    port, respectively.  You can also read these values to obtain the remote
    addressing parameters for the last received packet on the given UDP socket.
    Note that "SocketHandle" refers to the UDP socket handle returned by the
    UDPOpen() API, not the literal string "SocketHandle".
2.  Fixed ADC state save/restore bug in GenerateRandomDWORD() function in
    Helpers.c.  PIC24, dsPIC, and PIC32 platforms require the ADC ON/ADON bit to
    be cleared before modifying certain other ADC register contents.
3.  Fixed an ENC28J60 MAC/MII register write timing violation when using a
    PIC24H or dsPIC at over 33MIPS.  There was inadequate Chip Select hold time
    provided, violating the 210ns minimum specified in the ENC28J60 data sheet.
    This violation may have resulted in certain devices losing the ability to
    receive packets (due to the MARXEN bit, MACON1<0>, getting cleared
    unintentionally).
4.  Fixed an ENCX24J600.c driver bug in which operating at 100Mbps with the
    ENC424J600/624J600 Ethernet controller, it would be possible for the
    MACGetHeader() function to issue a Reset() operation under rare
    circumstances.  The PIC would reset whenever the PHY detected an illegal
    symbol during 4B5B decoding but guessed the correct 4B symbol such that no
    data corruption or CRC error occurred.  This condition results in a valid
    packet being received but with the Received Ok Receive Status Vector bit
    being clear (RSV<23> == 0).  This issue would become more probable when
    using very long Ethernet cables (ex: 100 meters) and receiving a lot of
    data.
5.  Fixed a TCP bug in which calling TCPDisconnect() to close a connection when
    the remote node's RX window was 0 bytes would have caused the stack to enter
    an infinite loop sending duplicate ACK packets.
6.  Fixed Wi-Fi bug that caused assert condition if too many management messages
    were being received during data traffic.
7.  Fixed Wi-Fi bug that caused WF_EVENT_CONNECTION_RESTABLISHED event case to
    send the wrong notification to the app.
8.  Fixed Wi-Fi bug that caused assert failure with Scratch move failure.
9.  Fixed Wi-Fi bug in WF_CAGetChannelList() and WF_CAGetSecurity that caused
    failure.
10. Fixed Wi-Fi EasyConfig bug that required development boards to be manually
    reset even after new network was selected.
11. Fixed MRF24WB0 bug that caused assert if invalid WPA/WPA2 key was entered.
12. Fixed Wi-Fi power management bit behavior in PS-Poll frame that was causing
    some AP’s to never send data or disconnect when in power save mode.
13. Fixed a TCP bug in which attempting to open a client TCP socket to a remote
    server, specified by IP address (not DNS address), that was offline, but
    who's MAC address was already cached by the ARP client, would result in
    endless back-offs. For example, when attempting to contact the remote node
    (that was not responding), the TCP module would have transmitted a SYN at
    time T=0 seconds, T=1s, T=3s, T=7s, T=15s, T=31s, T=63s, T=127s, T=255s,
    etc.  The exponential back-off between retransmissions would grow
    indefinitely until the retransmission interval would have grown so large
    that effectively no-retransmissions would be occurring.  Assuming the
    application wasn't written with its own timeout to prevent endless waiting,
    this would prevent the socket from automatically establishing the
    connection to the remote server once the server came back online.  With this
    TCP fix, the exponential back off now saturates after TCP_MAX_RETRIES (5)
    back offs and continues to retransmit using the same interval.  By default,
    this means SYN transmissions will occur at T=0 seconds, T=1s, T=3s, T=7s,
    T=15s, T=31s, T=63s, T=95s, T=127s, etc.  After 5 back-offs the
    retransmission interval stops growing and stays constant at 32 seconds.
14. Fixed an RSA computation bug that would cause the RSA module to never
    complete if you attempted to compute y = x^e % n where e = 3 (or similar
    number < 256 with only 0, 1, or 2 bits set).  Thanks go to Kevin Maidment
    for pointing this error out and suggesting a solution.  Note, that this fix
    to RSA.c is not distributed with the ordinary TCP/IP Stack due to United
    States export restrictions.  To get this fix, you must repurchase SW300052.
    This fix is included in SW300052 v2.6 or later.  If you don't have CD media
    to identify the SW300052 version that you have, you can test the RSA.c file
    that you have.  RSA.c in SW300052 v2.6 has a CRC32 checksum of 0x91F66711.
    RSA.c in v2.5 and prior had a checksum of 0xB1E8B0CC.

Known Problems:
1.  Telnet server module does not implement a lot of Telnet functions.  As a
    result, it will likely not display correctly or work at all with some Telnet
    clients.  The server was tested with the Microsoft telnet.exe utility which
    is provided with Microsoft Windows.
2.  If the DHCP client and DHCP server are used at the same time and you connect
    two similar boards to each other (ex: two PICDEM.net 2 boards connected via
    a crossover cable), a race condition can occur where both nodes will disable
    their DHCP server and neither board will get a successful DHCP lease.  If
    this unlikely scenario occurs, as a work around, simply reset one of the
    boards to reenable it's DHCP server.
3.  LCDBlocking.c timing for the LCD_E_IO enable signal is too fast to meet
    published data sheet limits for various LCD controllers when compiling for
    a PIC32 running at > 43MHz.  Despite this potential timing violation, the
    LCD does normally work correctly on the precompiled PIC32 demos for the
    Explorer 16 at 80MHz.

********
v5.25       07 May 2010
********
Changes:
1.  Added support for the Microchip MRF24WB0 802.11 WiFi controller (module
    part number MRF24WB0MA).  This product is intended as a backwards
    compatible, drop in replacement to the ZG2100.  The MRF24WB0MA should work
    with previous TCP/IP Stack versions as if it were a ZG2100M, but when the
    MRF24WB0MA is used with this (5.25) and future TCP/IP Stack versions,
    feature improvements inside the MRF24WB0 allow the TCP/IP Stack code/RAM
    size to be smaller and run faster.
2.  Dropped support for the ZeroG ZG2100 802.11 WiFi controller.  Applications
    that must stay with this device should continue to use TCP/IP Stack
    version 5.20b or earlier.  All new projects or preexisting projects
    undergoing updates should be developed with the MRF24WB0 instead.
3.  The WiFi connection management state machines now run on the MRF24WB0
    instead of the PIC host, freeing up code and data space.  Connection profiles
    can be created and the connection algorithm fine-tuned by the PIC
    application. In the WiFi demos see the WF_Connect function in MainDemo.c for
    an example of how to configure and then establish a WiFi connection.  The
    programming model has changed to an API model which is documented in
    'TCPIP Stack Help.chm'.
4.  Changed "VERSION" macro definition in TCPIP.h to "TCPIP_STACK_VERSION".
    "VERSION" is overly generic and will likely conflict with other identical
    tokens one may use in their application code or source libraries.
5.  Added support for the PIC24FJ256GA110, PIC24FJ256GB110 and PIC24FJ256GB210
    PIMs for the Explorer 16.  Note that when using the PIC24FJ256GA110
    general purpose PIM, the Ethernet PICtail Plus, Fast 100Mbps Ethernet
    PICtail Plus, MRF24WB0MA Wi-Fi PICtail Plus, or other SPI PICtail daughter
    board should be installed in the middle SPI2 slot of the Explorer 16, not
    the ordinary topmost SPI1 slot used by other PIMs, including the
    PIC24FJ256GB110 and PIC24FJ256GB210 ones.  The software is set up to use
    SPI2 for the PIC24FJ256GA110 PIM to avoid incompatibilities with silicon
    revision A3, which does not allow the SCK1 pin to be configured as a PPS
    output.
6.  Added support for the PIC24FJ256DA210 Development Board.
7.  Added TFTPUploadRAMFileToHost(), TFTPUploadFragmentedRAMFileToHost() and
    TFTPGetUploadStatus() APIs to the TFTPc.c file.  These APIs provide a very
    simple means of uploading a whole file to a remote TFTP server without
    requiring a great deal of application state machine logic.  These APIs
    require the DNS client module to be enabled (STACK_USE_DNS must be defined,
    in addition to STACK_USE_TFTP_CLIENT).
8.  Added a dummy DNS Server module.  This server always sends the local IP
    address in response to all queries received.  When using the PIC DHCP
    server, its purpose is to allow a user to type anything into a web browser
    (ex: http://asdf/) and still receive the web page provided by the PIC, much
    as a hotel or airport WiFi router will serve to you before you've paid or
    agreed to the network's terms of service.  This DNS server module is
    implemented in DNSs.c, requires one UDP socket, and is enabled via the
    STACK_USE_DNS_SERVER option in TCPIPConfig.h.
9.  Changed SPIFlash.h file defaults to target an SST SPI Flash with 4096 byte
    sectors instead of a Spansion Flash with 65536 byte sectors.  These new
    defaults are, among other reasons, in support of the PIC24FJ256DA210
    Development Board, which has an SST SST25VF016B on it.
10. Made TCP Keep-Alive packets consistently get sent TCP_KEEP_ALIVE_TIMEOUT
    (default 10 seconds) after the last socket TX or RX activity.  In earlier
    stack versions, if the local node transmitted some data and then let the
    socket go idle, the first Keep-Alive packet sent would use the
    TCP_START_TIMEOUT_VAL (default 1 second) timer value before getting sent.
    While benign in terms of application behavior, these faster than normal
    keep-alive transmissions were distracting when viewed in Wireshark or other
    packet capture tools.
11. Disabled STACK_USE_DYNAMICDNS_CLIENT option in TCPIPConfig.h by default for
    the TCPIP Demo App and TCPIP ENCX24J600 Demo App projects.  This option was
    enabled by default in earlier stack releases.  This was done to save code
    size and allow out-of-box compilation on devices with 128KB of Flash when
    not using compiler optimizations.  The TCPIP PIC32 ETH Demo App project
    continutes to have this option enabled by default.
12. Added SNMP v2 TRAP PDU format.  Macro SNMP_STACK_USE_V2_TRAP is used to
    enable the SNMP v2 trap format.  New API function SNMPV2TrapDemo() is
    included to support more than one variable binding to the SNMPv2 TRAP. This
    API can be used for a single SNMPv2 TRAP variable varbind and is part of
    CustomSNMPApp.c. A multiple variable binding demo can be enabled
    MainDemo.c.  One should not enable both SNMPTrapDemo and SNMPV2TrapDemo
    simultaneously.  Global flag "gSetTrapSendFlag" is used to indicate the
    start and end of SNMPv2 trap varbinds.  If gSetTrapSendFlag is FALSE, then
    very next variable varbind for the SNMPv2 TRAP, is the last or only one
    variable varbind.  If gSetTrapSendFlag is TRUE, then there is another
    variable varbind available to be part of the SNMPv2 TRAP PDU.
13. Added support for PIC32MX6XX/7XX external PHY's: SMSC 8700LAN and National
    DP83640.
14. Added schematics and BOM for the PIC32 Ethernet Starter Kit.
15. Added the Google PowerMeter demo project. Consult the "Reference
    Implementation for Google PowerMeter.chm" help file for more information.
16. Modified the SSL and TCP modules to create the TCPStartSSLClientEx function.
    This function will enable the SSL module to store supplementary data
    (currently only SSL Certificate Public Keys) in a structure.
17. Moved the HTTP_PORT, HTTPS_PORT, HTTP_MAX_DATA_LEN, and HTTP_MIN_CALLBACK_FREE
    macros from HTTP2.c to TCPIPConfig.h.

Fixes:
1.  The SPIFlashEraseSector() function in the SPIFlash.c file incorrectly erased
    the sector specified by the current write pointer (set by calling
    SPIFlashBeginWrite()) instead of the specified dwAddr parameter address.
    This error had no impact on any TCP/IP Stack code as these parameters always
    matched.  However, application code using the API would have been affected.
    Thanks go to Marc Boon for reporting this issue on the Microchip Ethernet
    forum.
2.  Fixed ENC424J600/624J600 driver for PSP modes 2, 4, 6, and 10.  The PIC's
    PMP PMMODE<9:8> bits were not set correctly.
3.  Removed from lingering references to TickGetDiff() in FTP.c, TFTPc.c and
    UARTConfig.c.
4.  Fixed DNS client module from returning the DNS server IP address if the DNS
    query failed due to a server error (i.e. DNS did respond, but did not
    return any records, such as when attempting to resolve a name that isn't in
    the DNS).  DNSIsResolved() will now return 0.0.0.0 on any non-recoverable
    DNS error or timeout.
5.  Fixed HTTP2 MPFS upload page being accessible from URLs that weren't an
    exact match.  For example, in 5.20 and earlier, accessing
    http://mchpboard/mpfsuploadASDF would still have opened the mpfsupload page.
    Thanks go to Andrea Rivolta on the Microchip Ethernet Forum for identifying
    this error.
6.  Improved UDP TX checksum code for the special case when the computed
    checksum was 0x0000.  According to the UDP RFC, for this corner case, the
    checksum should be converted to 0xFFFF before transmission to differentiate
    from the checksum disabled case, improving error detection by a minuscule
    amount.
7.  Fixed GetCLKOUT() function in ENCX24J600.c driver file.  Previously, 0x00
    would always be returned, regardless of the value in the COCON bits of
    ECON2.  The function documentation for SetCLKOUT() and GetCLKOUT() was also
    corrected (had obsolete information ported over from ENC28J60 driver file).
8.  Fixed DHCP client rebinding bug in which the DHCP client would request the
    wrong IP address if an unrelated DHCP OFFER or ACK message were received
    after we transmitted a DHCP REQUEST but before we received our DHCP ACK.
    Under rare conditions, this would have resulted in the TCP/IP stack
    reverting to the static or AutoIP assigned address for a few seconds
    between DHCP lease renewals.
9.  Fixed TFTP Internet Bootloader bug in which uncommon .hex files containing
    a certain data pattern could not be uploaded correctly to the PIC18F97J60
    family device.  For these problem .hex files, a block of 32 program words
    (64 bytes) would remain unprogrammed (left as 0xFFFF) due to a parsing error
    in the bootloader's DecodeHex() function.  The TFTP upload operation would
    succeed without reporting a programming error.  The problem can be detected
    by using an ICD3 or similar ICSP programmer and reading the program Flash
    out of a device that is programmed with the bootloader and application .hex
    files.  Compare the resulting memory dump to a device programmed only with
    the application .hex file.  If you have devices deployed in the field with
    the previous bootloader and happen to generate a  problem application .hex
    file, you can potentially work around the bootloader bug by opening the
    application .hex file with Notepad and appending dummy address records to
    the beginning to move the data around in the file.  For example, at the very
    top of the .hex file, add lines containing ":020000040000FA" until the
    bootload process works correctly.  You may alternatively try adding spaces
    at the end of any line, although this may make the .hex file incompatible
    with some programming utilities.  Thanks go to Jonathan Seidmann for
    identifying and reporting this bug.
10. Fixed SNMPv2 TRAP format issue where SNMP browser was displaying all the
    SNMPv2 traps as SNMP version 1.  SNMP v2 TRAP pdu format is rectified.
    Macro SNMP_STACK_USE_V2_TRAP is used to form and send a SNMPv2 TRAP PDU.
    SNMPTrapDemo API is used for both SNMPv1 and SNMPv2 single variable
    varbind trap.
11. Fixed an HTTP2.c server module initialization bug when using the
    PIC32MX7XX/6XX series internal Ethernet module.  During initialization the
    HTTPLoadConn() function would overwrite over 100 bytes of PIC RAM past the
    end of the reserved memory allocated for the HTTP2 module.  This problem
    would manifest itself by locking up the TCPIP PIC32 ETH Demo App-C32 demo
    shortly after power up if you compiled TCP/IP Stack version 5.20 with the
    MPLAB C Compiler for PIC32 MCUs (C32) version 1.11.
12. Fixed SSL client from incorrectly parsing for the server's public key in
    rare cases where the RSA Public Key Algorithm identifier was received, but
    the key hadn't been received by TCP yet.  Thanks go to Kevin Maimdnet for
    identifing this error in SSL.c and reporting it via
    http://support.microchip.com/.
13. Fixed Tick.c TickGet(), TickGetDiv256() and TickGetDiv64K() APIs sometimes
    returning the wrong value on PIC32 platforms.  On the PIC32MX3XX/4XX family
    devices a wrong return result would sometimes occur if using -O3 compiler
    optimizations (maximum speed) with the Microchip MPLAB C Compiler for PIC32
    MCUs (C32).  On the PIC32MX5XX/6XX/7XX family devices, such as the
    PIC32MX795F512L device used on the PIC32 Ethernet Starter Kit, wrong values
    could be returned, regardless of the compiler optimization level.

Known Problems:
1.  Telnet server module does not implement a lot of Telnet functions.  As a
    result, it will likely not display correctly or work at all with some Telnet
    clients.  The server was tested with the Microsoft telnet.exe utility which
    is provided with Microsoft Windows.
2.  If the DHCP client and DHCP server are used at the same time and you connect
    two similar boards to each other (ex: two PICDEM.net 2 boards connected via
    a crossover cable), a race condition can occur where both nodes will disable
    their DHCP server and neither board will get a successful DHCP lease.  If
    this unlikely scenario occurs, as a work around, simply reset one of the
    boards to reenable it's DHCP server.
3.  HI-TECH PICC-18 compilers are not supported in this release.  The supplied
    HI-TECH PICC-18 MPLAB projects usually will not compile and/or link.
4.  LCDBlocking.c timing for the LCD_E_IO enable signal is too fast to meet
    published data sheet limits for various LCD controllers when compiling for
    a PIC32 running at > 43MHz.  Despite this potential timing violation, the
    LCD does normally work correctly on the precompiled PIC32 demos for the
    Explorer 16 at 80MHz.

********
v5.20       18 November 2009
********
Changes:
1.  Added PIC32MX7XX/6XX Family integrated Ethernet controller support.  The
    "TCPIP PIC32 ETH Demo App" folder was added to compile for the PIC32
    Ethernet Starter Kit.  Ethernet driver files "ETHPIC32ExtPhy.c" and
    "ETHPIC32IntMac.c" were added, in addition to the "ETHPIC32ExtPhyDP83848.c"
    file, which is a specific driver file for the National DP83848 10/100 PHY.
2.  Added RFC 3927 Auto IP module.  This module will automatically assign a
    local IP address to the node in the 169.254.xxx.xxx private address range
    (subnet mask 255.255.0.0) if a DHCP server is not present on the network or
    the DHCP client is disable.  The exact IP address chosen will be
    pseudo-random, but as required by the protocol, it will perform gratuatous
    ARPs to avoid clobbering anyone else's IP address.  Also, unless there is an
    address collision with a preexisting node on the network, the IP address
    generated by the Auto IP module will not change between power cycle events
    (random number generator is seeded by local MAC address).  To enable this
    module, STACK_USE_AUTO_IP must  be defined in TCPIPConfig.h.  When compiled
    in, the module defaults to enabled, but will automatically yield to the
    DHCP client module, which has higher priority.
3.  Added "TCPIP MDD Demo App" beta application projects.  Projects in this
    folder store the HTTP2 web pages in external FAT16/FAT32 formatted SD card
    or USB Mass Storage media instead of an MPFS2 formatted EEPROM or SPI Flash.
    For more information on these projects, see the "Running the TCPIP MDD Demo
    App (Beta Release).pdf" file in the Microchip\Help folder.
4.  Expanded XEEReadArray() API's third length parameter from a BYTE to a WORD.
5.  Converted all variable declarations and type casts of TICK data type to
    DWORD.  The TICK typedef is now deprecated and will be removed in a future
    stack release.  This data type conflicts with the TICK structure used in
    certain other Microchip software libraries.
6.  Added TCP_WINDOW_UPDATE_TIMEOUT_VAL option to the TCP.c file (default
    200ms).  This timeout controls the time after calling TCPGet() or
    TCPGetArray() before the stack will transmit a RX window update to the
    remote node.  Historically, the TCP_AUTO_TRANSMIT_TIMEOUT_VAL value was
    used for this purpose (default 40ms).  This change decreases the net window
    update transmission overhead.  If this adversely affects your application
    RX performance (unlikely, but possible for certain communications patterns),
    set TCP_WINDOW_UPDATE_TIMEOUT_VAL equal to or shorter than
    TCP_AUTO_TRANSMIT_TIMEOUT_VAL to get the same or better behavior relative
    to previous stack versions.
7.  Split TCP_MAX_SEG_SIZE configuration constant in TCP.c into separate
    TCP_MAX_SEG_SIZE_TX and TCP_MAX_SEG_SIZE_RX configuration constants.
    Previously, TCP_MAX_SEG_SIZE was used to limit both the maximum size of
    transmit and receive packets.  In cases where large TX FIFOs are allocated,
    and the remote node advirtises a large Maximum Segment Size TCP option, this
    change improves TCP transmit performance by roughly 10%.
8.  Renamed "Internet Radio App", "Internet Bootloader App" and "WiFi Iperf
    App" folders to "TCPIP Internet Radio App", "TCPIP Internet Bootloader App"
    and "TCPIP WiFi Iperf App" respectively.  These new names ensure consistent
    folder placement when viewing the Microchip Solutions folder with other
    Microchip Application Libraries installed.

Fixes:
1.  Fixed SSL functionality (ex: HTTPS server) from failing when using the
    ENC424J600 and ENC624J600 Ethernet controllers.  In stack versions 5.00 and
    5.10, the BFSReg() and BFCReg() functions were being incorrectly used to set
    and clear CRYPTEN (EIR<15>).  ENC424J600/624J600 silicon errata #6 on
    production silicon revision A2 prevents BFSReg() and BFCReg() from being
    able to modify CRYPTEN.  This resulted in the SSL RSA encrypt/decrypt
    operations from ever finishing.  The ENC424J600/624J600 errata #6 workaround
    is now implemented in the ToggleCRYPTEN() function in ENCX24J600.c.
2.  Fixed an RSA padding error in the ENCX24J600.c's version of RSASetData() and
    RSASetE() functions.  This fixes the Bad Record MAC problem when using SSL
    client APIs with the ENC424J600 and ENC624J600, as mentioned in the 5.10
    stack release notes' Known Problems section.  Although unknown at the time
    of release this problem also occurred in stack version 5.00.
3.  Fixed DNS client from mishandling DNS responses that did not use name
    compression.  Thanks go to Will Stone on the Microchip Ethernet forum for
    identifying this bug.
4.  Fixed an ExtractURLFields() API bug which would incorrectly parse the URLs
    containing other URLs.  Ex:
    "http://www.google.com/search?q=http://www.microchip.com/"
5.  Fixed TickGet(), TickGetDiv256(), and TickGetDiv64K() APIs from potentially
    returning an incorrect time value (0x10000 ticks less than it should have)
    on rare occasions when using a PIC32 and with compiler optimizations turned
    on.  The Tick.c module was also revised so that the IEC0 register does not
    get written to via a load-modify-store operation on PIC32s so that it is
    now possible for other application ISR functions to write to IEC0 without
    risking state corruption.
6.  Fixed PIC32 Starter Kit Debugger losing access to the PIC32 target when the
    project was run.  JTAG was being disabled at run time, but the PIC32
    Starter Kit Debugger requires JTAG to communicate with the debug
    executive.  JTAG is now conditionally disabled on PIC32s when the
    __MPLAB_DEBUGGER_PIC32MXSK macro is undefined.
7.  Fixed a Berkeley sockets API bug in which calling closesocket() on a
    SOCK_STREAM type socket (TCP) did not actually close the socket if the
    remote node did not first send a FIN to the local node. This would leak a
    TCP socket each time the affected API calling sequence occurred and result
    in no FIN getting transmitted to the remote node.
8.  Fixed an HTTP2 filename parsing bug that would occur when a web browser
    submitted a request for a file with hex encoded characters in it.  For
    example, with stack version 5.10 and Firefox 3.5.3, typing
    "http://mchpboard/%70rotect" into the URL field would have resulted in an
    HTTP 404 not found error when "http://mchpboard/protect/index.htm" should
    have been returned instead.  Thanks go to Steve Tuttle for reporting this
    issue and suggesting a solution.
9.  Fixed a Berkeley sockets API bug in which calling recvfrom() on a datagram
    type socket (UDP) would return an incorrect remote IP address and port
    number when the from pointer was non-NULL.
10. Fixed HTTP2 server bug in which the HTTPReadPostName() function was failing
    to convert the field name from URL encoding to plain-text.  If the browser
    posted, for example, a field named "Stock Remaining", it would have been
    incorrectly returned from HTTPReadPostName() as "Stock+Remaining".
11. In Stack 5.10, any new values you saved into AppConfig via the Network
    Configuration demo web page would have been mishandled for WiFi projects.
    HTTPPostConfig() in CustomHTTPApp.c of the TCPIP WiFi Demo App and TCPIP
    Iperf Demo App projects were corrected so that they now write a magic 0x61
    marker into EEPROM/SPI Flash address 0x0000 to inidicate that the AppConfig
    structure is valid in EEPROM/SPI Flash.  This prevents the InitAppConfig()
    function in MainDemo.c from restoring the default settings when changing
    the values through the Network Configuration page.
12. For WiFi projects, a Gratuitous ARP Work-around was implemented to work
    around cases where access points send broadcast messages at data rates that
    the ZG2100 cannot listen to. The define USE_GRATUITOUS_ARP (in
    TCPIPConfig.h) turns this feature on or off.

Known Problems:
1.  Telnet server module does not implement a lot of Telnet functions.  As a
    result, it will likely not display correctly or work at all with some Telnet
    clients.  The server was tested with the Microsoft telnet.exe utility which
    is provided with Microsoft Windows.
2.  If the DHCP client and DHCP server are used at the same time and you connect
    two similar boards to each other (ex: two PICDEM.net 2 boards connected via
    a crossover cable), a race condition can occur where both nodes will disable
    their DHCP server and neither board will get a successful DHCP lease.  If
    this unlikely scenario occurs, as a work around, simply reset one of the
    boards to reenable it's DHCP server.
3.  HI-TECH PICC-18 compilers are not supported in this release.  The supplied
    HI-TECH PICC-18 MPLAB projects usually will not compile and/or link.
4.  ENC624J600 PSP modes 2, 4, 6, and 10 do not work at this time.  Some
    Parallel Bit Bang modes may not work either.  Some minor firmware changes
    are needed.
5.  TCPIP ENCX24J600 Demo App-C18.mcp project does not compile by default using
    MPLAB C Compiler for PIC18 MCUs (C18) version 3.34.  There is not quite
    enough program memory available on the PIC18F97J60 for the large number of
    selected stack features to allow linking.  To get this project to compile,
    turn on compiler optimizations or disable one of the modules in
    TCPIPConfig.h (ex: comment out STACK_USE_DYNAMICDNS_CLIENT).

********
v5.10       29 July 2009
********
Changes:
1.  Added SSL capability to the Telnet server.  If STACK_USE_SSL_SERVER is
    defined, the Telnet server will now listen on port 992 for SSL secured
    connections.  If you do not have a telnets client, you can use an SSL proxy,
    such as stunnel (http://www.stunnel.org/) to add SSL/TLS support to any
    telnet client.
2.  Moved a number of string pointer tables in the HTTP.c, HTTP2.c, FTP.c, and
    DynDNS.c files to allocate in ROM instead of RAM.  This reduces around 120
    bytes of RAM usage in the HTTP2 server when compiled for the PIC18 or
    PIC24/dsPIC platforms.  The gains are even greater on PIC32 platforms.
3.  Added redefinition of SPIRAM*(), SPIFlash*(), and XEEPROM*() functions so
    that when compiled and used without proper HardwareProfile.h definitions,
    a more descript linker error will be generated instead of a mysterious
    symbol not found error.
4.  Added several new APIs:
    - ExtractURLFields() in Helpers.c.  This function provides an easy
      means of parsing an URL string and extracting the protocol, hostname,
      port, file path, etc.  Currently, this function is commented out to save
      code space as no stack modules require it.  However, it should work
      correctly if you simply uncomment it (remove the #if 0...#endif around
      it).
    - strnchr() in Helpers.c.  Finds the first occurrence of a character within
      a string but limited to a maximum length before giving up.
    - TCPPeek() and TCPPeekArray() in TCP.c.  Reads from a TCP socket's RX
      FIFO buffer without removing the data from the stream.
    - TCPClose() in TCP.c.  Disconnects a socket from the remote node (if
      connected) and closes the socket handle, including for server type
      sockets.  This function is identical to the TCPDisconnect() API except
      for the handling of server sockets.  TCPDisconnect() returns server
      sockets to the listning state and maintains the socket handle.  TCPClose()
      closes the socket and frees all associated resources, invalidating the
      socket handle.
5.  Updated the DHCP client module:
    - Modified so that it wouldn't attempt to transmit DHCP Discover packets
      when the MAC layer reports no link (MACIsLinked() == FALSE).  This avoids
      main() while(1) loop performance degredation when you unplug the Ethernet
      cable or lose association to your access point.
    - Added capability of performing DHCP discovers and requests without
      setting the BOOTP broadcast flag.  Now, the DHCP client module will start
      up and attempt to obtain an IP address with the broadcast flag set, but
      if it fails the next DHCP retry will attempt to obtain the IP address
      with the broadcast flag cleared.  The flag will toggle back and fourth
      between unicast mode and broadcast mode if no DHCP server responds.  This
      feature improves compatibility with certain DHCP servers and WiFi access
      points.
    - Added several new APIs including DHCPInit(), DHCPIsEnabled(),
      DHCPStateChanged(), DHCPIsBound(), and DHCPIsServerDetected().
    - Removed the DHCPFlags DHCP_CLIENT_FLAGS global variable.  Use the above
      named APIs now to get equivalent functionality.
    - Removed the DHCPBindCount global variable.  To detect if the DHCP state
      has changed, poll the new DHCPStateChanged() function.
    - Removed the DHCPReset() API.  To perform this operation, now call the
      DHCPInit() API.  Use 0x00 for the vInterface parameter.
6.  Removed deprecated TickGetDiff() macro.  To get a tick difference, just
    subtract the two values in-line.  This macro was removed because it promoted
    confusing code.  Ex: a-b is different from b-a.  However, it was not
    contextually obvious which of the two was returned when TickGetDiff(a, b)
    was called.
7.  Added PIC32MX460F512L USB and dsPIC33FJ256GP710 PIM support to the Explorer
    16 hardware profile for the TCPIP WiFi Demo App and WiFi IPerf App projects.
8.  Added all files needed for SSL (assuming the crypto libraries are present)
    to the TCPIP WiFi Demo App-C30 and TCPIP WiFi Demo App-C32 projects.
9.  Converted TCPIP Demo App, TCPIP WebVend App, Internet Radio App, and
    Internet Bootloader App MPLAB Build Directory Policy to compile in the
    project folder instead of the source folder.  This reduces the depedancies
    on the MPLAB project include path and allows new projects to be created by
    copying one of the pre-existing folders (ex: copy "TCPIP Demo App" to
    "My App") without having problems including the wrong HardwareProfile.h and
    TCPIPConfig.h files.
10. Changed EEPROM/SPI Flash AppConfig record valid flag from 0x60 to 0x61 in
    the TCPIP WiFi Demo App and WiFi Iperf App projects.  This will force the
    various EEPROM settings to get erased when switching between Ethernet and
    WiFi projects.  This is done since the AppConfig structure changes when
    using WiFi (SSID string is added).
11. The Wifi Iperf App and TCPIP WiFi Demo App projects have been optimized for
    better performance.

Fixes:
1.  Fixed a TCPDisconnect() API bug in which the last few bytes of data (up to
    the TCP socket's TX FIFO size less 532 bytes) was not transmitted and no
    FIN was sent out if the TX FIFO was full of data when TCPDisconnect()
    was called.  This problem could have only occurred for TCP sockets with a
    large TX FIFO (>=532 bytes).  This problem could have been observed in
    stack version 5.00's "TCPIP Demo App-C32 EXPLORER_16 32MX360F512L ENC624J600
    PSP 9.hex" precompiled application, among others, if you connected to the
    TCPPerformanceTest.c module and then attempted to simultaneously access the
    web server.  The web server was returning data very slowly and failing to
    send the last parts of each file requested by the browser.
2.  Eliminted a potential buffer overflow vulnerability from the
    HTTPHeaderParseContentLength() function in HTTP2.c.  If an oversized or
    malformed Content-Length header is sent from the web client, the function
    will now gracefully fail by returning an HTTP 400 Bad Request error page.
    Thanks go to Mark Philipp for identifying this error and suggesting a
    solution.
3.  Fixed a TCPOpen() problem in which the stack would continuously flood the
    network with nearly back-to-back ARP query packets if a client socket was
    created that specified a non-reachable remote IP address (ex: local gateway
    was offline, or for destinations on the same subnet, the actual remote node
    was offline).  This problem would occur only after a few minutes (<10) had
    passed since the PIC was last reset.  Thanks go to Sergey of DPS TELECOM for
    reporting this problem.
4.  Fixed linking problem with BigInt_helpers.S (PIC24/dsPIC only) when
    targeting a PIC with more than 8KB of RAM.  The interface registers (_iA,
    _xA, _iB, _xB, _iR, and _wC) are now forced into near RAM.
5.  Cleaned up some uninitialized variable warnings in SNMP.c.
6.  Fixed a sequence variable traversal bug in SNMP.c.
7.  Cleaned up a large number of unsigned integer to signed integer comparison
    warnings produced by the MPLAB C Compiler for PIC18 MCUs (C18) version
    3.32.  With earlier versions of this compiler, these warnings would only be
    generated as messages, so they did not get displayed by default.
8.  Some ENCX24J600 parallel bit bang modes work now.  PSP Mode 5 indirect has
    been tested.
9.  SSL client and server capabilities now work when using the ZeroG ZG2100M
    WiFi interface.  In the 5.00 stack release, attempting to enable the
    STACK_USE_SSL_CLIENT or STACK_USE_SSL_SERVER TCPIPConfig.h options with
    this network controller would have resulted in an error trap.  If an LCD
    was present, the LCD would display “encRdPtrRAWId = encWrPtrRAWId” when the
    error occurred.
10. The WiFi Iperf App demo locked up when an invalid command was entered at
    the serial port console.  This is now fixed.
11. The WiFi Iperf App demo locked up when running with a PIC32 if iwconfig was
    typed at the serial port console.  This is now fixed.
12. The Wifi Iperf App demo, when running on the PIC24 and PIC32, and compiled
    with the –Os option (min code size optimization), did not work.  This is
    now fixed.
13. Change a lot of BerkeleyAPI.c internals.  This may fix a number of BSD
    API problems.
14. Fix a problem with SNMP variables being inaccessible with certain unique
    PEN numbers.

Known Problems:
1.  Telnet server module does not implement a lot of Telnet functions.  As a
    result, it will likely not display correctly or work at all with some Telnet
    clients.  The server was tested with the Microsoft telnet.exe utility which
    is provided with Microsoft Windows.
2.  If the DHCP client and DHCP server are used at the same time and you connect
    two similar boards to each other (ex: two PICDEM.net 2 boards connected via
    a crossover cable), a race condition can occur where both nodes will disable
    their DHCP server and neither board will get a successful DHCP lease.  If
    this unlikely scenario occurs, as a work around, simply reset one of the
    boards to reenable it's DHCP server.
3.  HI-TECH PICC-18 compilers are not supported in this release.  The supplied
    HI-TECH PICC-18 MPLAB projects usually will not compile and/or link.
4.  ENC624J600 PSP modes 2, 4, 6, and 10 do not work at this time.  Some
    Parallel Bit Bang modes may not work either.  Some minor firmware changes
    are needed.
5.  SSL client code doesn't work with ENC424J600/624J600 devices.  The remote
    server terminates the connection reporting a bad record MAC (Message
    Authentication Code).  The SSL client does work with other controllers.

********
v5.00       27 April 2009
********
Changes:
1.  Added ZeroG ZG2100 802.11 WiFi controller support.  The new TCPIP WiFi Demo
    App and WiFi Iperf App projects have been added, which default to using this
    controller.
2.  Added Microchip ENC424J600/624J600 10/100 Ethernet controller support.
    Support for this controller is provided by the new ENCX24J600.c/.h files
    which perform the same role as the ENC28J60.c/.h or ETH97J60.c/.h files.
    Precompiled .hex files for the ENC624J600 controller require the use of the
    new Fast 100Mbps Ethernet PICtail Plus daughter card (AC164132).  This
    product is not available at the time of the 5.00 TCP/IP stack release.
    However, it is anticipated to be available for purchase on
    www.microchipdirect.com in CQ3 2009.
3.  Significantly updated the Internet Radio App project.  Previously, radio
    stations were hard coded into program memory at compile time.  Now, a
    dynamic Shoutcast directory client has been implemented which allows
    retrieval of radio stations at run time, offering endless stations you can
    tune into.  The web pages for the radio have also been updated to allow
    control and status reporting of the board from a web browser.
4.  Update SNMP Server (Agent) module to support SNMPv2C.  The default Demo App
    web pages now include an SNMP reconfiguration capability to set the read
    and write community strings.
5.  Added ICMPSendPingToHost() and ICMPSendPingToHostROM() APIs to ICMP (ping)
    client module.  These two APIs are available only when STACK_USE_ICMP_CLIENT
    and STACK_USE_DNS is defined in TCPIPConfig.h.  These functions allow
    pinging of DNS hostnames directly without the need for the application to
    convert the hostname to an IP address first by manually calling the DNS
    client APIs.  With this addition, the PingDemo.c file was updated to ping
    the hostname "ww1.microchip.com" instead of a static IP address.  Previously,
    the PingDemo would stop working a couple of months after the stack was
    released, due to the IP address of the www.microchip.com server dynamically
    changing.  If the DNS module is not enabled, the ping demo will instead ping
    the local gateway IP address instead of ww1.microchip.com.
6.  Updated TCPPerformanceTest.c code.  The previous version would generate
    incorrect speed calculations at high data rates (ex: >1Mbyte/sec).
7.  Added multiple connection support to Telnet server example module.  To
    allow multiple connections, define MAX_SIMULTANEOUS_CONNECTIONS in Telnet.c
    greater than 1 and create an equal number of TCP_PURPOSE_TELNET type TCP
    sockets in the TCPSocketInitializer[] definition in TCPIPConfig.h.
8.  Added more randomness to the local port selection when opening a client-mode
    TCP socket.  This reduces the risk of reusing a previously used port number
    if the user power cycles the device.
9.  Updated XEE* SPI EEPROM API functions.  Writes are no longer required to
    start on an EEPROM page boundary, and writes can now be arbitrarily long
    without having to call XEEEndWrite() at each page boundary.  Additionally,
    the XEEWriteArray() API has been added, which performs a similar operation
    to the SPIFlashWriteArray() API (but with no special erase cases to worry
    about).
10. Decoupled AppConfig storage in external SPI EEPROM or SPI Flash option from
    MPFS_USE_EEPROM and MPFS_USE_SPI_FLASH options.  MainDemo.c will now save
    the AppConfig structure in external non-volatile memory, even if MPFS is
    unused (no HTTP or SNMP server modules enabled) or MPFS is using internal
    Flash program memory to store web pages/bib information.  This change also
    allows the XEE*() and SPIFlash*() non-volatile read/write functions to be
    available at all times (even if MPFS is unused), as long as the appropriate
    hardware pinout definitions are present in HardwareProfile.h.  SPI Flash and
    SPI EEPROM are no longer mutually exclusive with each other.  However, if
    both are enabled simultaneously, AppConfig will be stored in the EEPROM, not
    the SPI Flash.
11. Added required SSL files to TCPIP Demo App MPLAB projects.  SSL capabilities
    can now be turned on directly via the STACK_USE_SSL_SERVER and
    STACK_USE_SSL_CLIENT options in TCPIPConfig.h for these projects, assuming
    appropriate crypto libraries are installed (SW300052 available from
    https://www.microchipdirect.com/).  With this change, the historical "SSL
    Demo App" folder has been removed.
13. Updated HardwareProfile.h files.  This includes the addition of PIC18
    Explorer board support, removal of the PICDEM Z profile, changes to the
    HI-TECH PICC-18 profiles for newer compilers, among other changes.
14. Added a TCP and UDP performance test measurements table to TCPIP Stack
    Help (TCPIP Stack Help.chm).  Access this from the "Microchip TCP/IP Stack"
    book, "Stack Performance" page.
15. Updated MPFSlib project (Microchip.MPFS.dll file) so that C18 and C32 output
    from the MPFS2.exe utility is now identical for MPFS2 images.  The generated
    .c file is now compatible with both C18 and C32 compilers simultaneously.
    Previously, the images generated for C18 would compile successfully for C32
    projects, but would potentially operate incorrectly when compiler
    optimizations were turned on.  Images generated for C32 would compile
    successfully and work on C18 projects, but the C18 compiler would take a very
    long time to process the file each time you rebuilt your MPLAB project.  Now,
    the image generated for C18 matches the image generated for C32 and it will
    compile fast and work correctly on both platforms, even with compiler
    optimizations turned on.
16. Added schematics and BOMs for the Ethernet PICtail, Ethernet PICtail Plus,
    Fast 100Mbps Ethernet PICtail Plus, Internet Radio, PICDEM.net 2, and ZeroG
    ZG2100M PICtail development boards to the "Microchip\TCPIP Stack\Demo Board
    Files" folder.

Fixes:
1.  Fixed a denial of service vulnerability in the NBNSGetName() function of the
    NBNS.c file.  Previously, if a deliberately malformed packet was received,
    the PIC RAM could have become corrupted.  Thanks go to David Talmage for
    finding this vulnerability.
2.  Fixed Timer1 interrupt flag clearing code on PIC32 products.  Previously,
    the Tick.c module was clearing the interrupt flag in an unsafe manner which
    could have corrupted other interrupt flags in the IFS0 register.  Thanks go
    to Leon van Snippenberg working on the AVIX-RT RTOS for pointing this error
    out on the Microchip forums.
3.  Fixed SNMP up-time variable.  Previously the CustomSNMPApp.c module would
    respond with the number of Tick API ticks that elapsed, not the number of
    10ms time slices that elapsed.  The SNMP standard uses 10ms as its time base.
4.  Fixed BigInt_helper.asm's _masBI() and _masBIROM() functions when the Br
    parameter's length modulo 4 was equal to 1 or 2.  This bug previously caused
    the BigIntMod() function to sometimes go into an endless calculation loop on
    PIC18 products when using the SSL libraries and certain combinations of
    modulus data and length were used.  Thanks go to Vasil Stoianov on the
    Microchip Ethernet forum for running into this defect and reporting it.
5.  Fixed SSLSessionNew() so that it wouldn't "lose" SSL sessions after waiting a
    few hours.  This would previously make it impossible to make new SSL
    connections after a while, but then after a few more hours, the sessions
    would become free again.  Thanks go to Jim Stephens for identifying this
    issue and finding the solution.
6.  Fixed an SSL 2.0 antique client hello record length calculation bug occurring
    when a received record was > 255 bytes.
7.  Added retransmission capability to SendNotification() function in
    CustomSNMPApp.c.  Previously, if an SNMP trap were sent, but the initial ARP
    query or response was lost on the network, the SendNotification() code would
    have deadlocked, and suppressed all future transmission of SNMP traps.
8.  Fixed DNS client timeout if the DNS server is unable to be ARPed.
    Previously, the DNS client would retry ARPing the DNS server indefinitely if
    it was offline.  Now, the DNS client will correctly abort if too many
    attempts to ARP the DNS server fail.  Thanks go to Phil "andersop" on the
    Microchip Ethernet forum for identifying this error.
9.  Suppressed transmission of a TCP RST packet to an unknown IP or MAC address
    if the TCPDisconnect() function was called on a client mode socket that was
    not finished with ARP or DNS resolution yet.  Thanks go to Phil "andersop" on
    the Microchip Ethernet forum for pointing this behavior out.
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

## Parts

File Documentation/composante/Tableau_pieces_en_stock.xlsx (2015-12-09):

INVENTAIRE DES PIÈCES DISPONIBLES
Pièces | Manifacturer | Manifacturer Part | Caractéristiques | Prix unité | Quantité | Prix total/pièce | quantité utilisé
PIC 18LF26k22 | Microchip | PIC18LF26K22-I/SS-ND |  | 3.79 | 11 | 41.69 | 0
Regulateur 3,3v | Texas Instrument | 296-28778-1-ND |  | 0.82 | 11 | 9.02 | 3 | (1 brulé)
Crystal | CTS-Frequency Controls | CTX1164CT-ND |  | 0.76 | 12 | 9.12 | 0
Connecteurs | Sullins | PREC040SAAN-RC | 40 pins | 0.68 | 3 | 2.04 | 1
Connecteurs Male | Assmann | HRP10H-ND |  | 0.62 | 11 | 6.82 | 0
Câble rectangulaire | Assmann | H3CCS-1006M-ND |  | 1.49 | 1 | 1.49 | 0
FLASH | Microchip | SST25VF010A-33-4C-SAE-ND |  | 0.82 | 12 | 9.84 | 2
EEPROM | Microchip | 25AA02E48-I/SN-ND |  | 0.58 | 12 | 6.96 | 2
Push Button | C&K Component | CKN9112CT-ND |  | 0.27 | 15 | 4.05 | 4
Résistance | Susumu | RR12P100DCT-ND | 100 | 0.14 | 50 | 7.00 | 4
Résistance | Susumu | RR12P4.7KDCT-ND | 4,7K | 0.14 | 50 | 7.00 | 4
Battery Holder | Keystone | 2479K-ND | 3 batteries AAA | 2.48 | 10 | 24.80 | 1
Condensateur | Samsung | 1276-1246-1-ND | 1uF | 0.12 | 25 | 3.00 | 2
Condensateur | Samsung | 1276-1109-6-ND | 10pF | 0.12 | 25 | 3.00 | 4
Condensateur | Samsung | 1276-1007-1-ND | 0,1uF | 0.12 | 50 | 6.00 | 18 | (2 jettés)
Led | Kingbright | 754-1131-1-ND | Vert | 0.19 | 15 | 2.85 | 2
Led | Kingbright | 754-1135-1-ND | Jaune | 0.19 | 15 | 2.85 | 0
Led | Kingbright | 754-1128-1-ND | Rouge | 0.19 | 15 | 2.85 | 2
LCD | Newhaven Display Intl | NHD-C0216CZ-FSW-FBW-3V3 |  | 13.26 | 1 | 13.26 | 0
FTDI Bridge RS232 | FTDI | 768-1135-1-ND | *Déjà en stock | 2.47 | 2 | 4.94 | 0
Connecteur DB9 |  |  |  | 0 | 2 | 0.00 | 0
Battery AAA | FDK America.inc | LR03RS | Alkaline | 0.45 | 15 | 6.75 | 3
 |  |  |  |  | Total | 175.33
PAR AGATHE
Jumper |  |  |  | 5 |  |  | 1
Nouvelle commande
PIC 18f46J50 | microchip | PIC18F45J50-I/PT |  |  | 12 |  | 1
Switch slide | C&K Component | JS202011SCQN |  |  | 20 |  | 1
micro USB-B | FCI | 10118192-0001LF |  |  | 13 |  | 1
Condensateur | YAGEO | CC0805ZKY5V6BB106 | 10uF |  | 25 |  | 1
Crystal | Abracon LLC | AB26TRQ-32.768KHZ-T |  |  | 15 |  | 1
Écran | Newhaven Display Intl | NHD-C0216CZ-FSW-FBW-3V3 |  |  | 6 |  | 0
Résistance | YAGEO | RC0805JR-0736KL | 36k 5% |  | 10 |  | 0
Chargeur | microchip | MCP73871-2CCI/ML |  |  | 8 |  | 0
Régulateur | Texas Instrument | LM3671MF-3.3/NOPB | 3,3V |  | 10 |  | 0
Push Button | C&K Component | PTS645SM43SMTR92 LFS |  |  | 15 |  | 0
Condensateur | Samsung | CL21F104ZBCNNNC | 0,1uF |  | 50 |  | 0
Résistance | YAGEO | RC0805JR-07110KL | 110k 5% |  | 10 |  | 0
Résistance | Stackpole | RNCP0805FTD40k2 | 40,2k 1% |  | 10 |  | 0
Résistance | Stackpole | RNCP0805FTD10k0 | 10k 1% |  | 10 |  | 0
Bobine | TDK corporation | MLZ2012A2R2M | 2,2uH 650mA 150ohm |  | 10 |  | 0
Résistance | Stackpole | RNCP0805FTD2k00 | 2k 1% |  | 10 |  | 0
Condensateur | YAGEO | CC0805ZRY5V6BB475 | 4,7uF |  | 25 |  | 0
Résistance | Stackpole | RNCP0805FTD1k00 | 1k 1% |  | 100 |  | 2 | 2 for JONATHAN
Led | Kingbright | APT2012EC | rouge |  | 10
Led | Kingbright | APT2012SGC | vert |  | 10
Bobine | KEMET | L0603C3N9SRMST | JONATHAN |  | 2 |  | 2
Bobine | AVX | HLC025R6BTTR | JONATHAN |  | 2 |  | 2
Bobine | EPCOS | B82496C3829J | JONATHAN |  | 2 |  | 2

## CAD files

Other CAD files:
MASTER/Exemple Miwi/v2015_08_10/apps/miwi/miwi_mesh/miwi_demo_kit/firmware/miwi_demo_kit.X/dist/miwikit_pic18f46j50_24j40/production/miwi_demo_kit.X.production.obj
SLAVE/Exemple Miwi/v2015_08_10/apps/miwi/miwi_mesh/miwi_demo_kit/firmware/miwi_demo_kit.X/dist/miwikit_pic18f46j50_24j40/production/miwi_demo_kit.X.production.obj

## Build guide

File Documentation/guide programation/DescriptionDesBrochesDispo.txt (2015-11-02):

Description des Pins disponnibles sur le connecteur I/O des Boards Capteur

Pin 19 (J1.1) = Digital I/O. Analog Input 0.
Pin 20 (J1.2) = Digital I/O. Analog Input 1. 
Pin 21 (J1.3) = Digital I/O. Analog Input 2.
Pin 22 (J1.4) = Digital I/O. Analog Input 3.
Pin 10 (J1.5) = Digital I/O. Analog Input 8.
Pin 11 (J1.6) = Digital I/O. Analog Input 9.
Pin 05 (J1.7) = Digital I/O
Pin 41 (J1.8) = Digital I/O.
Pin 25 (J1.9) = Digital I/O. Analog Input 5.
Pin 26 (J1.10) = Digital I/O. Analog Input 6.

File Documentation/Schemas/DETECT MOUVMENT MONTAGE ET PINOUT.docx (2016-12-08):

PIN OUT DÉTECTEUR DE MOUVEMENT DG75

N.C COM +12 GND TAMPER TAMPER

MONTAGE

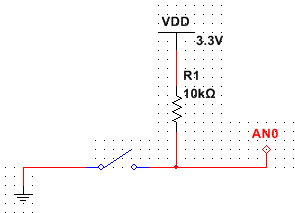
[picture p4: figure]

NC (fil brun

Com (fil jaune)

Détecteur de mouvement

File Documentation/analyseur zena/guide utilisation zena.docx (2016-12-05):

# Introduction

Comment utilizer l’analyseur zena

Lancer l’application et ouvrir MiWi(TM) Tools

---> Network traffic Monitor

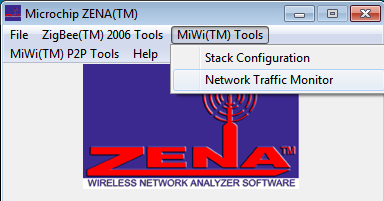
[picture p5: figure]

Sur la fenêtre MiWi™ Network Monitor

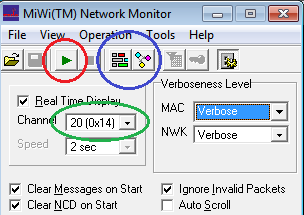
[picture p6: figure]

Le Channel doit être sur 20(0x14)

Le Play commence l’analyse

# Utilisation du network message packet sniffer

L’icône ouvre la fenêtre

Les 3 donnés les plus pratique sont souvent le Dest PAN, Dest Addr et le Source addr. Le Dest PAN confirme l’adresse du réseau PAN auxquelles sont connecté les appareils. Le Dest Addr est l’adresse du ou des destinataires et le Source addr donne l’adresse de celui qui envoie le message. Les adresses données sont générées par le PAN coordonnateur qui lui a par défaut l’ID 0x0000. Comme dans le schéma ou A représenté le coordonnateur et la distribution des adresses des appareils qui s’y connectent.

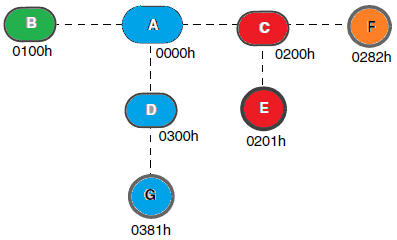
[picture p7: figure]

# Séquence de lancement d’une appareil (coordinateur, capteur, étudiant ou professeur)

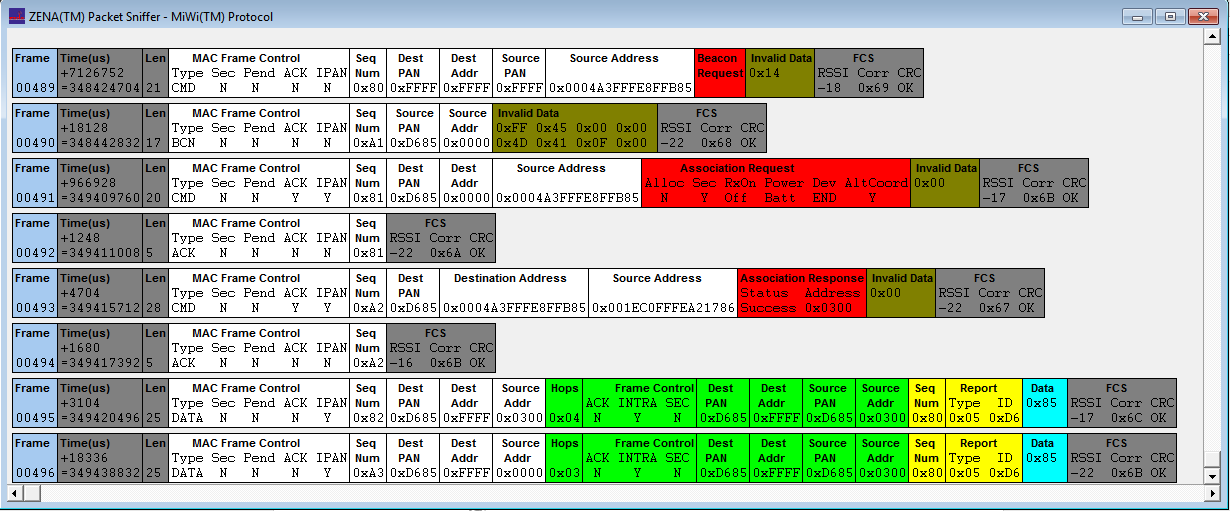
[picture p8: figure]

Où l’appareil démarré essaie de communiquer à un coordonnateur pour qu’il y assigne une adresse.

Puis la réponse du coordonnateur

Où l’adresse assigné est visible dans le Dest Addr

# Utilisation de l’analyseur network configuration display

L’icône ouvre la fenêtre

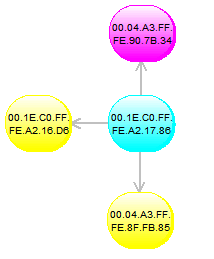
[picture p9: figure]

Dans cette exemple on peut voir le coordonnateur, une carte capteur et deux cartes (étudiant, professeur) où les flèches indiquent le sens des communications.

Document fait par

Jean-Philippe Dagenais

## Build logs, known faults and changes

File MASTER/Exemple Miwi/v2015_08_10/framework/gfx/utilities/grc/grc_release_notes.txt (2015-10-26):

Graphics Resource Converter (GRC) 
Release Notes

Version 4.02.00

Bug Fixes

* Corrected the bitmap header offset for externally stored resources.

Changes

* Added space attribute to declarations that use space __prog__ to comply with XC16 warning message since XC16 v1.22.
* Changed GFX_LIB_CFG_* definitions to GFX_CONFIG_* to match Graphics Library.

Version 4.01.00

New Features:

*  When the reference source file is generated, there is a graphics library version check. This has been changed to check for a graphics library resource format check. This aligns the JAVA application to the resource format version of the graphics library firmware.

Version 4.00.39

Bug Fixes

* Updated Bitmap file support

New Features:

* Added support for unified output for internal storage.
  * Source file out contains the header information
  * Assembly file contains the resource information.

Version 3.29.06

Bug Fixes

* Corrected a bug with storing external palettes.

Version 3.28.15

Bug Fixes

* Support for command line palette resources has been added.
  * Palettes must be gpl files
* Corrected the color depth, bpp, of the header structure when used the auto-palette and compression.
* Various typos.

New Features

* Swapped the bit orientation for the 1bpp bitmap images. The previous versions of the GRC placed the left most pixel at the MSB. This has been changed to place the left most pixel at the LSB. The change was made to accommodate controllers that have windowing. This also makes the pixel orientation consistent with the pixel orientation of 4bpp images.
* Allow for padding and non-padding bitmap images. Bitmap images are padded which means that each horizontal line will start on a byte boundary. The option has been added to allow for conversion of bitmap resources to be non-padded which allows the least resource space and controllers with windowing that auto increments to use them.
  * NOTE: The non-padded feature is not supported by all of the controllers. Please verify that the controller supports non-padded bitmap images before using.
* Added support for the XC32 aand XC16 compilers.
  * NOTE: Support for C30 and C32 is still present.
* C30/XC16 font resource data placement.
  * Placed internal font data in program memory. If the font data or a combination of font data resources exceed the 32k limit, a define, USE_GFX_FONT_IN_PROGRAM_SECTION, should be defined in graphics configuration header. This will place the font resource data in program memory space.
* Added the extended glyph support to installed fonts.

Version 3.17.47

Bug Fixes

* Support for command line binary resource conversion to C array has been fixed.
* For C30 compilers version greater than 3.25, the "page" attribute was added to generated resources using the C array conversion.
* Able to loading TTF fonts from a GRP (obsolete) project file.
* Can detect is an IPU compression will be greater than the original compression size.

New Features

* Added a compile time check for the IPU compressed and decompressed defined sizes. The the defined values for the compressed and decompressed buffer sizes in HardwareProfile header files are less than the compressed and decompressed buffer sizes of the generated resources, there will be a compile time warning. This warning should be address to make sure that proper decoding of IPU images can occur.
* Font filter phrases that are exact duplicates will be discarded and if the label names are the same, but the phrase character offsets are not, a warning will be given.
* Font support of extended glyph table entry. For TTF fonts that have non-unicode characters, support for rendering these characters. These characters are usually located in the extended ASCII range (128-255). The TTF font file dialog will allow the user to select extended glyph. It is the user's responsibility to understand if the TTF font contains characters in the upper ASCII range that need this feature.
* Font support of anti-alaising. For installed and TTF fonts, anti-alaising support has been added.
* Current limitation when using fonts stored in EDS space, they can not be anti-aliased.
* Batch files have been created to launch the GRC jar file. Some computers made have the "jar" extension associated with another type of program.
* Added a command line argument to return the version of the GRC.
* Added a command line argument to selected the chip select used by the EDS memory space.
* Placed the CRC and marker at the end (last address) of the HEX file.
* Able to detect and warning the user if the label name conflicts with standard C syntax.
* Added a progress window when loading large projects.
* Added a block compression ability. The user can select the resources to compress, right mouse click and select the type of compression through the drop-down menu.
* The user can add a comment block to TTF and installed fonts. This allows the suer to insert any licensing that might be needed.

Version 3.08.21

Bug Fixes

* Added support for font filter files that have multiple line lists.
* Took out the backslash ("\") file separator to make it compatible across OS platforms.
* Correct numerous spelling errors.
* When setting RLE for a bitmap image and that image can not be used for RLE, the image would not be a part of the resources to convert after exiting the settings dialog box.
* When changing the settings, the resources would change in position.
* If a font was after a bitmap image in the resource table, the font compression would match the bitmap compression, even though fonts are not able to be compressed.
* The uncompressed size accounted from padding bytes.
* Skip over the BOM marker of the font filter, was producing a "?" character for the first string phrase label.
* In the Setting dialog box, when selecting the graphics module, the graphics bits per pixel could still be set.
  * When the graphics module is selected, the graphics bits per pixel is grayed out and set to 16bpp.
* In the HEX address dialog box, the user is able to use upper and lower case letter for the starting address.
  * For example: ff or FF
* Corrected the offset calculations for the external memory conversion when using compression.
* When entering the font point size in the font options dialog box, the font preview will be updated by either pressing <enter> or <tab>.

New Features

* Added command line support to parse a project file (xml)
* Added a check sum (CRC) to the external HEX files. A CRC is generated and placed in the first 8 bytes of the external HEX file. The first four bytes are used to verify that the CRC data is present. These four bytes will always read 'M', 'C', 'H', 'P'. The next four bytes are a 32-bit generated CRC. The header file produced will have the 32-bit CRC value that can be matched to the one in external memory to verify that it is valid.
* When loading a project, check to make sure that all of the files exist. If file(s) do not exist, ask the user if they would like to search to resolve the missing file.
  * If the user does not want to resolve the file, then do not load the project.
  * If the user resolves the file(s), ask them if they would like to save the project using the newly resolved files.
    * Gives the option to re-name the project as well.
* Check font filter files for a delimiter, "//". If there is not a delimiter present notify the user.

Documentation

* Added the command line interface documentation to the help file.

Version 3.03.01

Bug Fixes

* Drop-down combo box to choose the starting and ending character range in the font option dialog
  * The character display has been fixed to show the correct character representation.
* When loading projects that reference files that do not exist.
  * The user will be given the option to delete the resource of the non-existent file and keep all valid resources or remove all resources.
  * The project file will not be modified until the user selects to save the project.

Version 3.03

New Features

* Multiple bits per pixel (bpp) output support. Based on the graphics controller, the GRC can output the conversion in 16 or 24 bpp. This feature does not limit input sources. For example, if the output conversion is set to 16bpp and a 24bpp btimap image is being converted, the image will be converted to a 16bpp image.
* Conversion of bitmap images that are in 16bpp format. The GRC will convert bitmap images saved in x555 or 565 color format. The GRC will also up convert those images to 24bpp if converted as 24bpp Graphics Module.
* The reference header file generated after converting resources will now contain a #define of the images width and height in pixels.
* Generation of a palette from multiple bitmap images.
  * Added reading of comments from the GIMP file.
  * Allow the user to load a GIMP file to set comments
  * Created a header file with the symbol names of the palette colors
* Added Run Length Encoding (RLE) support for bitmaps that are 4bpp and 8bpp.
* Added support for Font Filter files that are saved in a UTF-8 format.
* The converter is able to converter raw binary data into a C array, hex file or binary file.
  * Drag and drop support is available.
* Added drag and drop support for project files.
* Added command line support.
  * Allows a user to run the converter tool from the command line interface without invoking the GUI.
* Changed the function buttons, like project load and save, to tool bar buttons.
* Use internal Inflate JAVA library
  * Support multiple operating systems.

Version 3.00

* When importing images (BMP and JPEG), the user can select multiple files in the file dialog box to import.
* Drag-and-drop is supported to import images.
* The application supports selective resources to convert.
* New installed font chooser.
* Projects are saved in xml format.
* Projects will save installed font information.
* Source file output (C Array) for fonts, has the font character glyph in the comments.
* Source file output has a table of contents for easier object searching.
* Font filtering will check to make sure that the selected character range is supported by the selected font.
* Multiple operating system platform support
* New GUI interface.
* Support for IPU unit.
  * This is only supported by PIC microcontroller with graphics modules.
  * Only supported on Microsoft Windows operating systems.
* The font underline style has not been added to this version.
  * The work around for this is to create the font without any underline style and after drawing the characters at runtime, use the primitive line function to add the underline.

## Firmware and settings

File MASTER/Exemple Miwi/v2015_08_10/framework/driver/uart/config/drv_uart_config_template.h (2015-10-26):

/**************************************************************************
  Company:
    Microchip Technology Inc.
  File Name:
    drv_uart_config_template.h
  Summary:
    UART Driver Configuration Template.
  Description:
    UART Driver Configuration Template
    
    These file provides the list of all the configurations that can be used
    with the driver. This file should not be included in the driver.       
  **************************************************************************/
//DOM-IGNORE-BEGIN
/*******************************************************************************
Copyright (c) 2012 released Microchip Technology Inc.  All rights reserved.

Microchip licenses to you the right to use, modify, copy and distribute
Software only when embedded on a Microchip microcontroller or digital signal
controller that is integrated into your product or third party product
(pursuant to the sublicense terms in the accompanying license agreement).

You should refer to the license agreement accompanying this Software for
additional information regarding your rights and obligations.

SOFTWARE AND DOCUMENTATION ARE PROVIDED AS IS WITHOUT WARRANTY OF ANY KIND,
EITHER EXPRESS OR IMPLIED, INCLUDING WITHOUT LIMITATION, ANY WARRANTY OF
MERCHANTABILITY, TITLE, NON-INFRINGEMENT AND FITNESS FOR A PARTICULAR PURPOSE.
IN NO EVENT SHALL MICROCHIP OR ITS LICENSORS BE LIABLE OR OBLIGATED UNDER
CONTRACT, NEGLIGENCE, STRICT LIABILITY, CONTRIBUTION, BREACH OF WARRANTY, OR
OTHER LEGAL EQUITABLE THEORY ANY DIRECT OR INDIRECT DAMAGES OR EXPENSES
INCLUDING BUT NOT LIMITED TO ANY INCIDENTAL, SPECIAL, INDIRECT, PUNITIVE OR
CONSEQUENTIAL DAMAGES, LOST PROFITS OR LOST DATA, COST OF PROCUREMENT OF
SUBSTITUTE GOODS, TECHNOLOGY, SERVICES, OR ANY CLAIMS BY THIRD PARTIES
(INCLUDING BUT NOT LIMITED TO ANY DEFENSE THEREOF), OR OTHER SIMILAR COSTS.
*******************************************************************************/
//DOM-IGNORE-END

#ifndef _DRV_UART_CONFIG_TEMPLATE_H
#define _DRV_UART_CONFIG_TEMPLATE_H

//#error "This is a configuration template file.  Do not include it directly."

// *****************************************************************************
// *****************************************************************************
// Section: Core Functionality Configuration Options
// *****************************************************************************
// *****************************************************************************

/*************************************************************************
  Summary:
    Macro controls operation of the driver for defining the size of the TX
    buffer
  Description:
    UART Byte mode internal buffer TX size configuration
    
    This macro controls the operation of the driver for defining the size
    of the TX buffer                                                      
*/

#define DRV_UART1_CONFIG_TX_BYTEQ_LENGTH        4
#define DRV_UART2_CONFIG_TX_BYTEQ_LENGTH        4
#define DRV_UART3_CONFIG_TX_BYTEQ_LENGTH        4
#define DRV_UART4_CONFIG_TX_BYTEQ_LENGTH        4


/*************************************************************************
  Summary:
    Macro controls operation of the driver for defining the size of the RX
    buffer
  Description:
    UART Byte mode internal buffer RX size configuration
    
    This macro controls the operation of the driver for defining the size
    of the RX buffer                                                      
*/

#define DRV_UART1_CONFIG_RX_BYTEQ_LENGTH        4
#define DRV_UART2_CONFIG_RX_BYTEQ_LENGTH        4
#define DRV_UART3_CONFIG_RX_BYTEQ_LENGTH        4
#define DRV_UART4_CONFIG_RX_BYTEQ_LENGTH        4


// *****************************************************************************
/*  Summary:
    Macro controls operation of the driver for Baud rate configuration

  Description:
    UART Baud Rate configuration

    This macro controls the operation of the driver for Baud rate.
*/

#define DRV_UART1_CONFIG_BAUD_RATE
#define DRV_UART2_CONFIG_BAUD_RATE
#define DRV_UART3_CONFIG_BAUD_RATE
#define DRV_UART4_CONFIG_BAUD_RATE


// *****************************************************************************
/* Sets the UART for 8-N-1 configuration

  Summary:
    Macro defines the line control mode to 8-N-1 configuration

  Description:
    This macro defines the line control mode as 8 data bits, none parity and 1
    stop bit. 
*/

#define DRV_UART1_CONFIG_8N1
#define DRV_UART2_CONFIG_8N1
#define DRV_UART3_CONFIG_8N1
#define DRV_UART4_CONFIG_8N1


// *****************************************************************************
/* Sets the UART for 8-N-2 configuration

  Summary:
    Macro defines the line control mode to 8-N-2 configuration

  Description:
    This macro defines the line control mode as 8 data bits, none parity and 2
    stop bit.
*/

#define DRV_UART1_CONFIG_8N2
#define DRV_UART2_CONFIG_8N2
#define DRV_UART3_CONFIG_8N2
#define DRV_UART4_CONFIG_8N2
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

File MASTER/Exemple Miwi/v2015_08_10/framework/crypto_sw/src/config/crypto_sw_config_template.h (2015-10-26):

/******************************************************************************
 Software License Agreement:

 The software supplied herewith by Microchip Technology Incorporated
 (the "Company") for its PICmicro(r) Microcontroller is intended and
 supplied to you, the Company's customer, for use solely and
 exclusively on Microchip PICmicro Microcontroller products. The
 software is owned by the Company and/or its supplier, and is
 protected under applicable copyright laws. All rights are reserved.
 Any use in violation of the foregoing restrictions may subject the
 user to criminal sanctions under applicable laws, as well as to
 civil liability for the breach of the terms and conditions of this
 license.

 THIS SOFTWARE IS PROVIDED IN AN "AS IS" CONDITION. NO WARRANTIES,
 WHETHER EXPRESS, IMPLIED OR STATUTORY, INCLUDING, BUT NOT LIMITED
 TO, IMPLIED WARRANTIES OF MERCHANTABILITY AND FITNESS FOR A
 PARTICULAR PURPOSE APPLY TO THIS SOFTWARE. THE COMPANY SHALL NOT,
 IN ANY CIRCUMSTANCES, BE LIABLE FOR SPECIAL, INCIDENTAL OR
 CONSEQUENTIAL DAMAGES, FOR ANY REASON WHATSOEVER.
********************************************************************/

#if !defined (_CRYPTO_SW_CONFIG_H)
#define _CRYPTO_SW_CONFIG_H
 
/****************************************************************************************************************************/
/* Block Cipher Configuration options (AES, TDES, XTEA)                                                                     */
/****************************************************************************************************************************/
// Defines the largest block size used by the ciphers you are using with the block cipher modes of operation
#define CRYPTO_CONFIG_SW_BLOCK_MAX_SIZE      16ul

// Defines the maximum number of block cipher handles
#define CRYPTO_CONFIG_SW_BLOCK_HANDLE_MAXIMUM  10u
 
/****************************************************************************************************************************/
/* AES Configuration options                                                                                                */
/****************************************************************************************************************************/

// Supported key lengths.  Select one of these four key length options for your application.
 
#define CRYPTO_CONFIG_SW_AES_KEY_DYNAMIC_ENABLE         // Dynamically determine key length at runtime
#define CRYPTO_CONFIG_SW_AES_KEY_128_ENABLE           // Use 128-bit key lengths
#define CRYPTO_CONFIG_SW_AES_KEY_192_ENABLE           // Use 192-bit key lengths
#define CRYPTO_CONFIG_SW_AES_KEY_256_ENABLE           // Use 256-bit key lengths.  Enabling this will actually enable CRYPTO_CONFIG_SW_AES_KEY_DYNAMIC_ENABLE

#endif      // _CRYPTO_SW_CONFIG_H

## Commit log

2015-10-19 Example MiWi Mesh
    mla v2015_08_10
    [miwi_demo_kit.X.production.obj]
2015-10-19 initial commit - take 2
    [miwi_demo_kit.X.production.obj]
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2015-10-19 Modifié la hiérarchie de l'exemple miwi demo kit
    [miwi_demo_kit.X.production.obj]
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2015-10-26 Remove MiWi Example
    l'exemple ne fonctionnait pas....
    Je vais ré-importer une version fonctionnelle
    [miwi_demo_kit.X.production.obj]
2015-10-26 Exemple MiWi!
    [miwi_demo_kit.X.production.obj]
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2015-10-27 add MASTER et SLAVE
    add MASTER et SLAVE
    [miwi_demo_kit.X.production.obj]
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2015-10-27 only main modified
    Created master and slave from 1st version. Cnly main been modified.
    Master almost ready. Slave not ready
    [miwi_demo_kit.X.production.obj]
2015-10-31 The Master and the slave auto connect on power on (ch20)
    Modified the main for the Master and the Slave. Both auto connect to
    each other. Cleaned the program. Ready for the pull request.
    [miwi_demo_kit.X.production.obj]
2015-10-31 changed the path to fit with the master branch
    no changes in the files
    [miwi_demo_kit.X.production.obj]
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2015-11-02 regulateur + chargeur
    ajout multisim
    [liste des prix.xlsx]
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2015-11-02 Add multisim
    Add multisim
    [liste des prix.xlsx]
2015-11-02 Ajouter Design2(Laurent) avec les footprint
    Ajouter Design2(Laurent) avec les footprint
    Quelqu'un doit fusionner les multisims pour avoir les footprint du
    Design2(Laurent) dans le DesignFinal(Etienne)
2015-11-02 Compilation files
    nothing new, only compilation files been modified
    [miwi_demo_kit.X.production.obj]
2015-11-02 Finale_Multisim
    J'ai finis tout, j'ai mis des diodes les LED ( a cause de footprints) Si
    j'ai manquer de quoi, faite moi signe! J'vous aime
2015-11-02 added Tableau_pieces_en_stock.xlsx
    [Tableau_pieces_en_stock.xlsx]
2015-11-03 Schemas Ultiboard (2 essais)
    2 tentatives de schémas ultiboard. C'est pas faisable esti... :P
2015-11-04 Mise à jour du schéma et de la base de données
    Mise à jour du schéma et de la base de données
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2015-11-09 update liste de pièce + schémas
    La liste de pièce est à jour pour ce qui a été utilisé. Les valeurs des
    condos et des résistances ont été mis à jour dans les schémas.
    [Tableau_pieces_en_stock.xlsx]
2015-11-10 Modifications du 9 novembre
    Travail fait avec Gabriel, Laurent & Jonathan.
    Mergé le slave et le master pour avoir un seul projet.
    [miwi_demo_kit.X.production.obj]
2015-11-10 path change
    creation dossier archive
    [miwi_demo_kit.X.production.obj]
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2015-11-10 changements sur le main
    [miwi_demo_kit.X.production.obj]
2015-11-23 modification PAN + modif Ultiboard + update pieces
    correction des erreurs du Ultiboard. Mise à jour des pieces en stock.
    Création d'un PAN
    [Tableau_pieces_en_stock.xlsx, miwi_demo_kit.X.production.obj]
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2015-11-23 Creating Individual files for each node
    [miwi_demo_kit.X.production.obj]
2015-11-24 version_1 3D case sensors(not printable yet)
    [Sensor-case.skp, Sensor-case_v1.skp, Sensor-case~.skp]
2015-11-24 SENDING PACKETS IS WORKING
    Can't select end device in miwi-config.h (errors)
    [miwi_demo_kit.X.production.obj]
2015-12-01 incorporation projecteur
    modification du cours du 30 nov
    [miwi_demo_kit.X.production.obj]
2015-12-07 Timer & Interrupt help file
    Pour aider les étudiants avec les timers & interrupts
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2015-12-07 Added the buzzer interrupt informations.
    RCONbits.IPEN = 1;
    T4CON = 0b00111111;
    PR4 = 156;
    IPR3bits.TMR4IP = 1;
    INTCONbits.GIEH = 1;
    PIR3bits.TMR4IF = 0;
2015-12-07 Assigned Buzzer to pin B2.
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2015-12-08 interface
    chengement du lundi le 7
    [miwi_demo_kit.X.production.obj]
2015-12-08 Sensor case ready to print!!
    [Sensor-case-bottom_v2.skp, Sensor-case-bottom_v2.stl, Sensor-case-bottom_v2_fixed.stl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]
2015-12-08 teacher
    modification du 8 dec
    [miwi_demo_kit.X.production.obj]
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2015-12-09 schéma du PCB étudiant
    Le schéma multisim et ultiboard de la carte étudiante est terminée
    (fonctionnelle, mais non optimisé)
    [Tableau_pieces_en_stock.xlsx]
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2015-12-14 Merged files from all branches.
    [miwi_demo_kit.X.production.obj]
2015-12-14 UPDATE QUESTIONNAIRE, ALARM, BUZZER
    [miwi_demo_kit.X.production.obj]
2015-12-21 update des schémas + pieces en stock. Version finale
    le tableau des pieces en stock est out of date. les schémas sont
    fonctionnels
    [Tableau_pieces_en_stock.xlsx]
2016-10-13 2016-10-13
    Added shortcut to program
    [miwi_demo_kit.X.production.obj]
2016-10-13 Whats going on?!?
    Tentative de réconstituer un programme fonctionnel.
    [miwi_demo_kit.X.production.obj]
2016-11-03 Exemple de code par Claude Barbaud
    Exemple de UART matériel et logiciel ainsi qu'interrupt
    Par Claude Barbaud
2016-11-03 Réorganisation de la documentation
    Ménage dans les dossiers de documentation.
    Ajout de la documentation du détecteur de mouvement
2016-11-03 Détecteur de mouvement - guide d'utilisation
    Information concernant le détecteur de mouvement
2016-11-07 UART logiciel
    Uart logiciel fonctionnel avec code de Claude
    [miwi_demo_kit.X.production.obj]
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2016-11-07 Ajout demo detecteur mouvement
    Un code pour le détecteur de mouvement a été ajouté
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2016-11-10 Demo sync
    Sync des demo
    [miwi_demo_kit.X.production.obj]
2016-11-14 Module Porte
    Ajout de l'information sur le fonctionnement du module Porte avec
    l'electro-aimant
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2016-12-08 réorganisation du master
    recommit du master
    [miwi_demo_kit.X.production.obj]
2016-12-08 derniere reorganisation des fichiers
    (caca fesse fesse)
    [miwi_demo_kit.X.production.obj]
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2017-05-16 changements du coding=utf-8 ditionnaire chemins pour fichiers probleme de pression
